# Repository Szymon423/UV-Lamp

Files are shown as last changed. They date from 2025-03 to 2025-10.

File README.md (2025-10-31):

<div align="center">

# 💅 UV Lamp Project

*A custom-made UV lamp for nail polish curing*

</div>

---

## 📖 About

In this project, I wanted to address a common issue in the beauty industry: **misleading UV lamp specifications**. 

Most commercial UV lamps are advertised as "60W UV lamps" while being supplied with only 15W power adapters. I wanted to create something honest and effective, so I designed this lamp from scratch.

### ✨ Key Features

- **True 45W electrical power** - honest specifications
- **Adjustable power settings** - customize intensity from 0-100%
- **Configurable timer** - set precise curing times up to 3 minutes
- **Intuitive touchscreen interface** - easy configuration with rotary encoder
- **Settings persistence** - preferences saved in flash memory
- **Professional UV wavelength** - 395-405nm LEDs for optimal curing

<div align="center">

### 🎨 Main Design

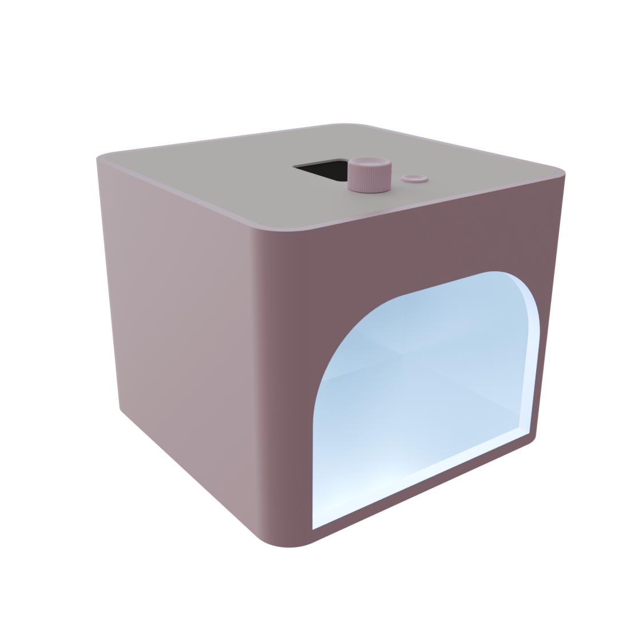
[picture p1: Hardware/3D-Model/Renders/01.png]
Main Render


### 🖼️ Detailed Views

<table>
  <tr>
    <td width="50%">
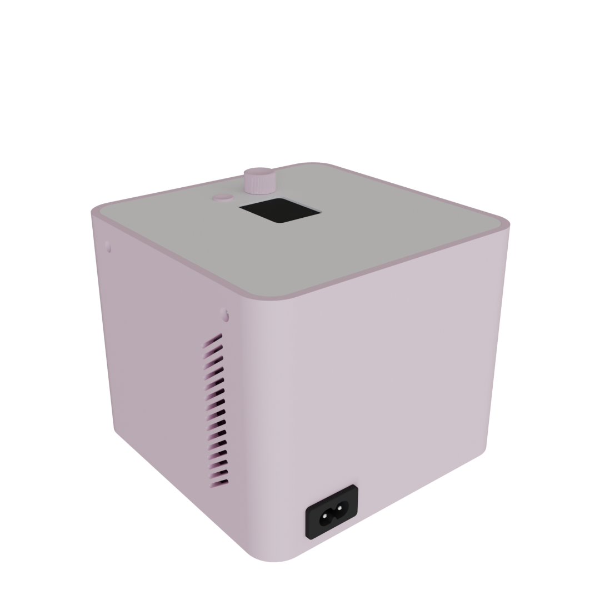
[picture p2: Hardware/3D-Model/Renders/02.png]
View 2
      
    </td>
    <td width="50%">
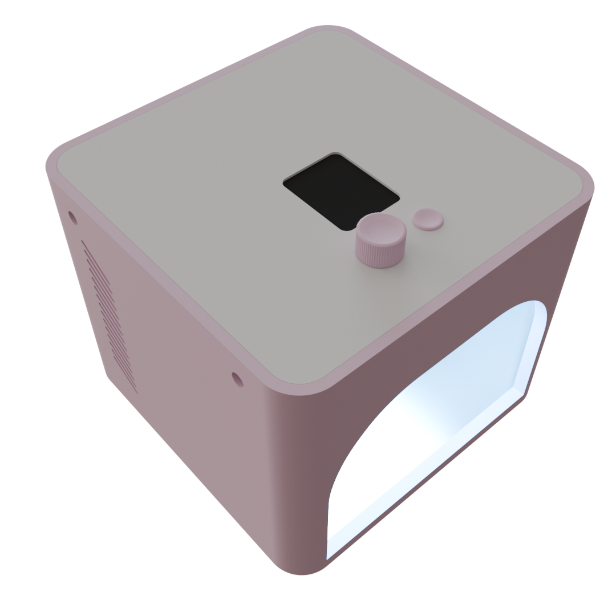
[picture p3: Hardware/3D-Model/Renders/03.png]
View 3
      
    </td>
  </tr>
  <tr>
    <td width="50%">
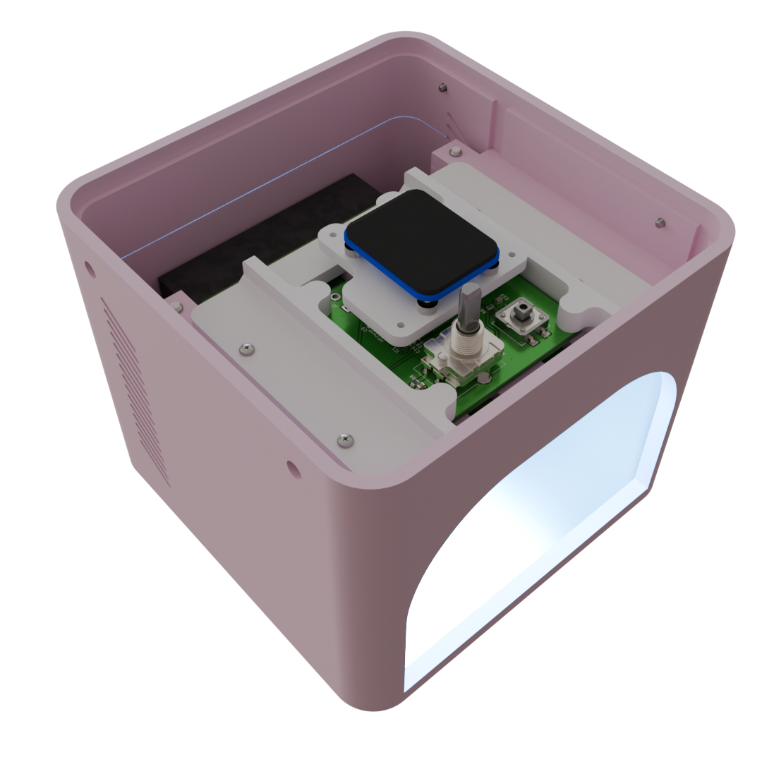
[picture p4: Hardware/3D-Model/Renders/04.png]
View 4
      
    </td>
    <td width="50%">
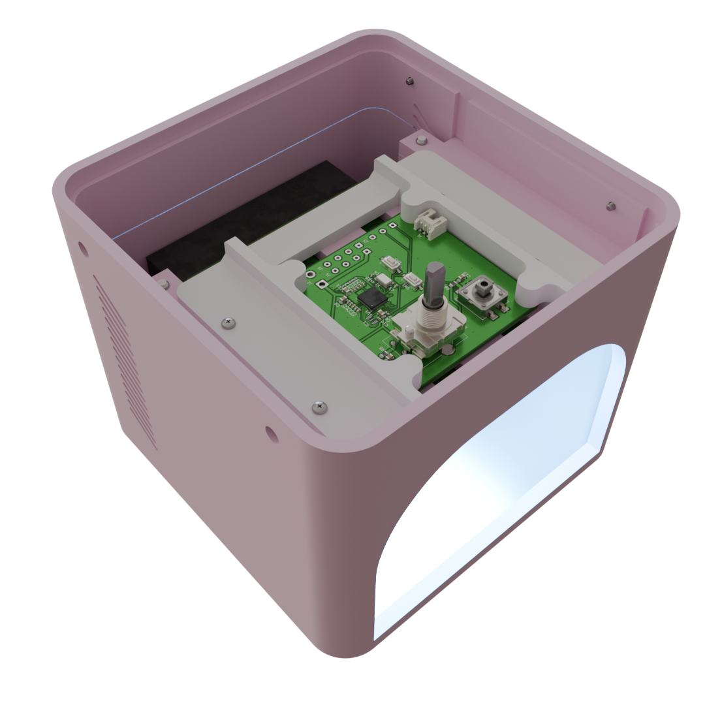
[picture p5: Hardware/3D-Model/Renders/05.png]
View 5
      
    </td>
  </tr>
  <tr>
    <td width="50%">
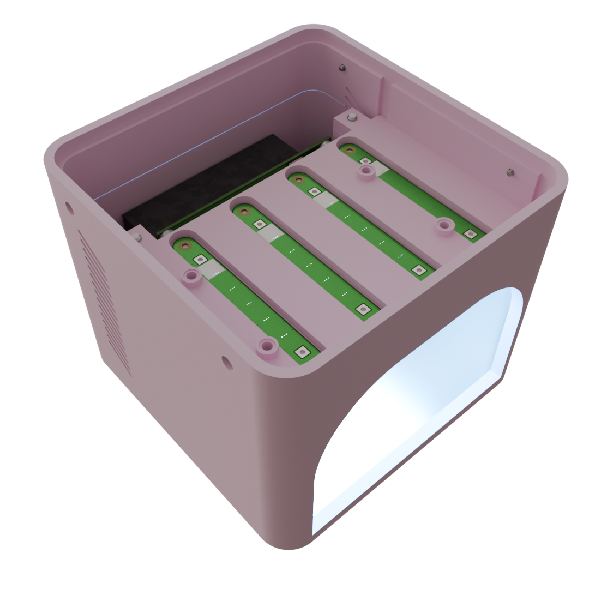
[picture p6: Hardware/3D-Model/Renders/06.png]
View 6
      
    </td>
    <td width="50%">
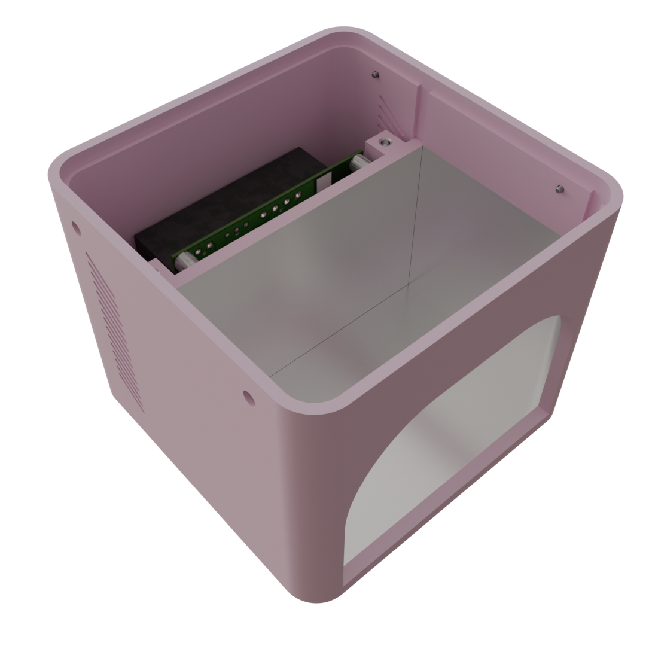
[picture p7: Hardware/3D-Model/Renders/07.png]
View 7
      
    </td>
  </tr>
  <tr>
    <td width="50%">
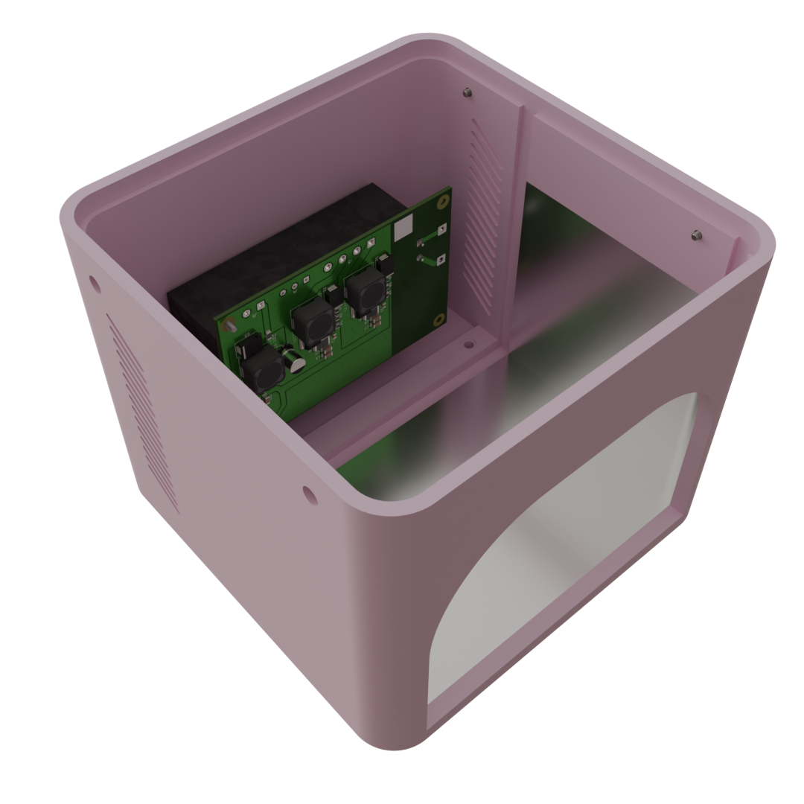
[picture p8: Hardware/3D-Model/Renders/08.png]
View 8
      
    </td>
    <td cwidth="50%">
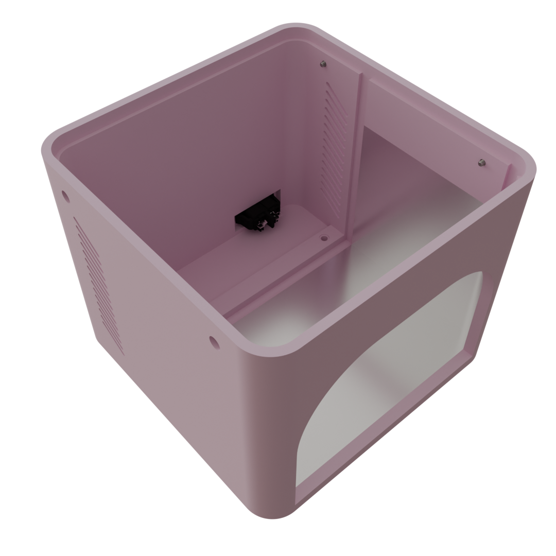
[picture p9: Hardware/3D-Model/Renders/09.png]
View 9
      
    </td>
  </tr>
</table>

</div>

---

## ⚡ Hardware Design

The hardware was designed in **KiCad** around the **Raspberry Pi RP2040** microcontroller. The lamp is powered through a C8 socket connector from 230V AC mains.

### 🔧 PCB Architecture

The system consists of three types of PCBs:

1. **Power & Driver Board**
   - Converts 230V AC to 48V DC for LED drivers
   - Provides 3.3V DC for microcontroller and peripherals
   - LED current drivers with PWM control capability

2. **Control Board**
   - RP2040 microcontroller
   - 1.69" LCD display with LVGL interface
   - Rotary encoder for navigation
   - Two control buttons
   - Flash memory for settings storage

3. **LED Arrays**
   - Multiple LED strings with 395-405nm wavelength
   - Optimized thermal management
   - Uniform light distribution

### 📊 Technical Specifications

- **Input voltage:** 230V AC (50/60Hz)
- **LED power:** 48V DC, up to 45W total
- **UV wavelength:** 395-405nm
- **Control:** PWM dimming, 0-100%
- **Timer range:** 0-180 seconds
- **Display:** 1.69" color LCD (280x240)

---

## 💻 Software

The firmware is written in C for the RP2040 and utilizes the following technologies:

### 🛠️ Core Technologies

- **LVGL (Light and Versatile Graphics Library)** - for the graphical interface
- **SquareLine Studio** - for UI design
- **Pico SDK** - official Raspberry Pi development kit
- **Hardware PWM** - for precise LED dimming control

### 🖥️ User Interface

<div align="center">

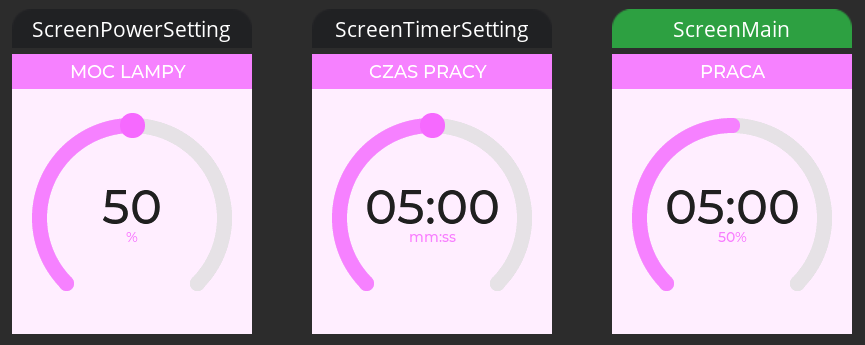
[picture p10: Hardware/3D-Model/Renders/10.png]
User Interface


</div>

The interface features three main screens:

1. **Main Screen** - displays current timer and power settings with arc progress indicator
2. **Power Configuration** - adjust UV intensity from 0-100%
3. **Timer Configuration** - set curing time from 0 to 180 seconds

### 🎮 Controls

- **Rotary Encoder** - navigate and adjust values
- **Button 1** - short press: change screen | long press: enter/exit edit mode
- **Button 2** - short press: start/pause timer | long press: reset timer

### 🚀 Features

- Smooth animations and transitions
- Real-time countdown with arc visualization
- Automatic settings save to flash memory
- Debounced button inputs with long-press detection
- 30 FPS refresh rate for fluid UI

---

## 📜 License

This project is open source. Feel free to use, modify, and distribute according to the license terms.

---

## 🙏 Acknowledgments

This project was created because my girlfriend complained about her unreliable UV lamp. It combines my passion for electronics and design with practical problem-solving.

---

<div align="center">

*Made with dedication to quality and honesty*

</div>

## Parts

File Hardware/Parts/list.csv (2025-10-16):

Symbol klienta | Symbol | Oznaczenie producenta | Producent | Ilość | Jednostka | Cena netto | Cena brutto | Wartość netto | Wartość brutto | Waluta
 | B3FS-4055P | B3FS-4055P | OMRON Electronic Components | 1 | szt | 4.89 | 6.01 | 4.89 | 6.01 | PLN
 | PEC16-4220F-S0024 | PEC16-4220F-S0024 | BOURNS | 1 | szt | 14.38 | 17.69 | 14.38 | 17.69 | PLN
 | IRM-60-48 | IRM-60-48 | MEAN WELL | 1 | szt | 54.88 | 67.5 | 54.88 | 67.5 | PLN
 | 3413.0119.22 | 3413.0119.22 | SCHURTER | 5 | szt | 1.744 | 10.73 | 8.72 | 10.73 | PLN
 | KAF31GR72A225KU | KAF31GR72A225KU | KYOCERA AVX | 10 | szt | 0.8 | 9.84 | 8 | 9.84 | PLN
 | ZSC00BM1011EARL | ZSC00BM1011EARL | VISHAY | 10 | szt | 0.643 | 7.91 | 6.43 | 7.91 | PLN
 | B560C-13-F | B560C-13-F | DIODES INCORPORATED | 4 | szt | 1.775 | 8.73 | 7.1 | 8.73 | PLN
 | DE1207-22 | DE1207-22 | FERROCORE | 5 | szt | 1.386 | 8.53 | 6.93 | 8.53 | PLN
 | CRCW080515K4FKTABC | CRCW080515K4FKTABC | VISHAY | 100 | szt | 0.0106 | 1.3 | 1.06 | 1.3 | PLN
 | CRCW0805316KFKTABC | CRCW0805316KFKTABC | VISHAY | 100 | szt | 0.1067 | 13.12 | 10.67 | 13.12 | PLN
 | SMD0805-36.5K-1% | 0805S8F3652T5E | ROYALOHM | 100 | szt | 0.0692 | 8.51 | 6.92 | 8.51 | PLN
 | ERA6AEB1152V | ERA6AEB1152V | PANASONIC | 10 | szt | 0.215 | 2.64 | 2.15 | 2.64 | PLN
 | TPS54560DDA | TPS54560DDA | TEXAS INSTRUMENTS | 1 | szt | 25.75 | 31.67 | 25.75 | 31.67 | PLN
 | 0805B822K500CT | 0805B822K500CT | WALSIN | 10 | szt | 0.166 | 2.04 | 1.66 | 2.04 | PLN
 | LM3409HVMY/NOPB | LM3409HVMY/NOPB | TEXAS INSTRUMENTS | 2 | szt | 9.28 | 22.83 | 18.56 | 22.83 | PLN
 | DMP10H400SK3-13 | DMP10H400SK3-13 | DIODES INCORPORATED | 3 | szt | 1.9167 | 7.07 | 5.75 | 7.07 | PLN
 | DE1207-47 | DE1207-47 | FERROCORE | 5 | szt | 1.334 | 8.21 | 6.67 | 8.21 | PLN
 | ERA6AEB6811V | ERA6AEB6811V | PANASONIC | 10 | szt | 0.212 | 2.61 | 2.12 | 2.61 | PLN
 | AR0805-24K9-0.1% | AR05BTCW2492 | Viking | 10 | szt | 0.433 | 5.32 | 4.33 | 5.32 | PLN
 | SMD0805-49K9-1% | 0805S8F4992T5E | ROYALOHM | 100 | szt | 0.0612 | 7.53 | 6.12 | 7.53 | PLN
 | CS2512-0R3-1%-HP | CS12FTFSR300 | Viking | 10 | szt | 1.152 | 14.17 | 11.52 | 14.17 | PLN
 | C0805C471K5RAC | C0805C471K5RACTU | KEMET | 100 | szt | 0.0629 | 7.74 | 6.29 | 7.74 | PLN
 | C0805C471K5RAC | C0805C471K5RACTU | KEMET | 100 | szt | 0.0629 | 7.74 | 6.29 | 7.74 | PLN
 | VS-30BQ100-M3/9AT | VS-30BQ100-M3/9AT | VISHAY | 10 | szt | 1.361 | 16.74 | 13.61 | 16.74 | PLN
 | PK2B-3LLE-GNVM | PK2B-3LLE-GNVM | ProLight Opto | 11 | szt | 6.04 | 81.72 | 66.44 | 81.72 | PLN
 | PK2B-3LLE-GNV | PK2B-3LLE-GNV | ProLight Opto | 11 | szt | 6.04 | 81.72 | 66.44 | 81.72 | PLN

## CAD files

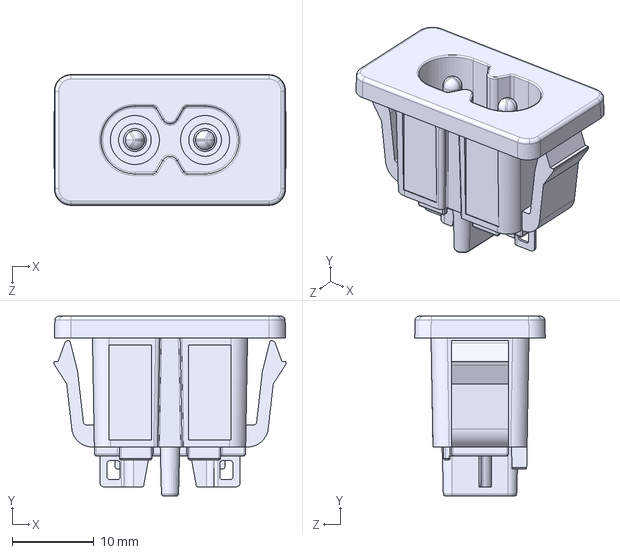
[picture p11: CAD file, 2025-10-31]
Hardware/3D-Model/Assets/4300-0102/4300.0102.stp
28.4 x 22.0 x 16.0 mm

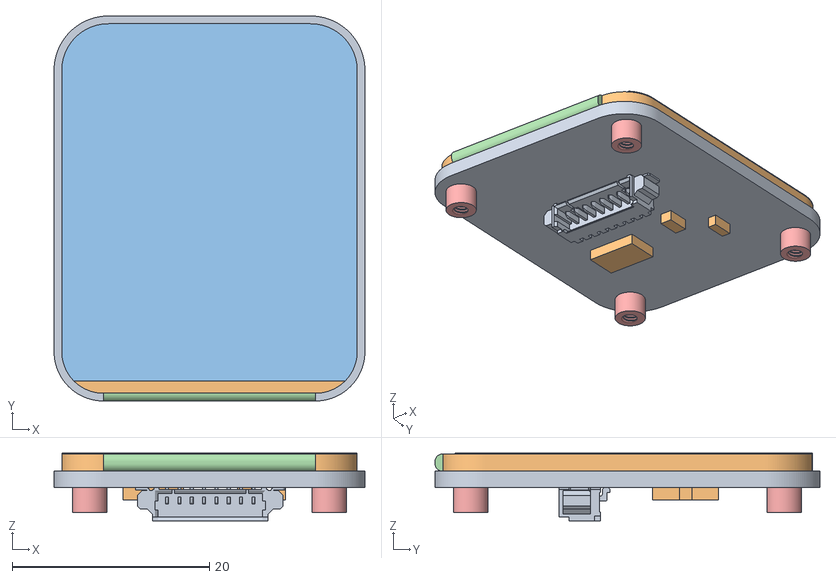
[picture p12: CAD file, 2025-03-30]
Hardware/3D-Model/Assets/WAVESHARE 1.69in IPS LCD.obj
31.5 x 39.0 x 6.88
obj1
obj2
obj3
obj4
obj5

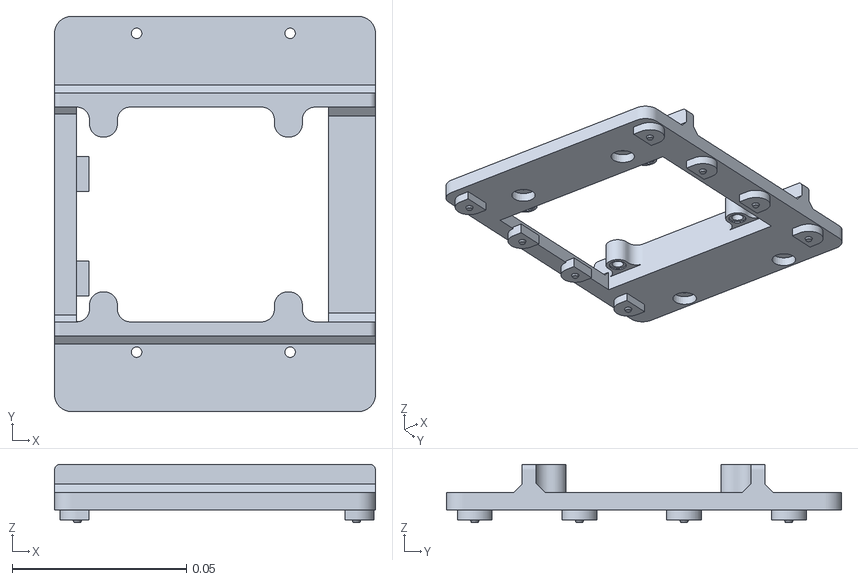
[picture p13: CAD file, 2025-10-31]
Hardware/3D-Model/Print-Models/03.stl
0.092 x 0.113 x 0.0167

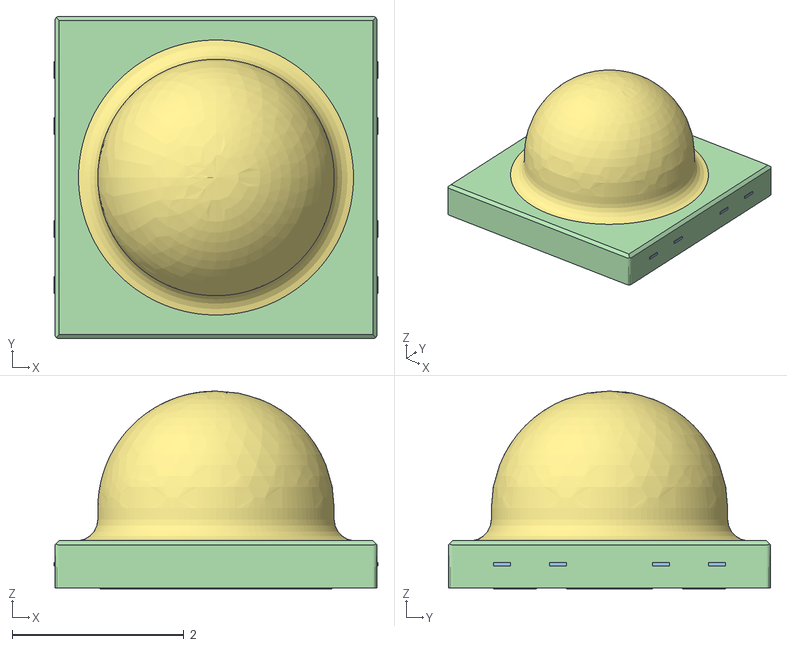
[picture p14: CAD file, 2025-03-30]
Hardware/3D-Model/Assets/LR H9GP.obj
3.77 x 3.75 x 2.30
obj1
obj2
obj3
obj4
obj5
obj6
obj7

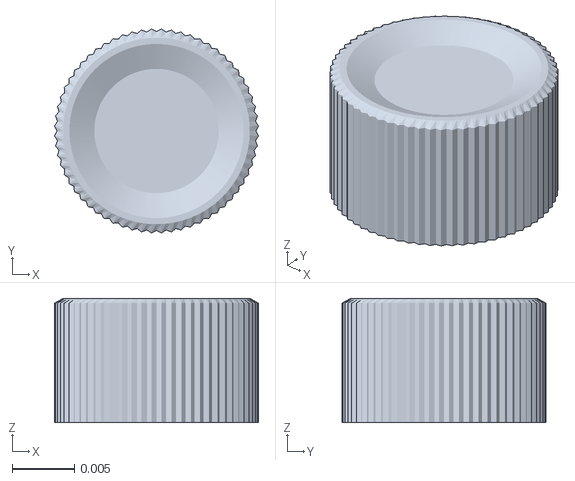
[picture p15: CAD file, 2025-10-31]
Hardware/3D-Model/Print-Models/08.stl
0.0164 x 0.0164 x 0.01

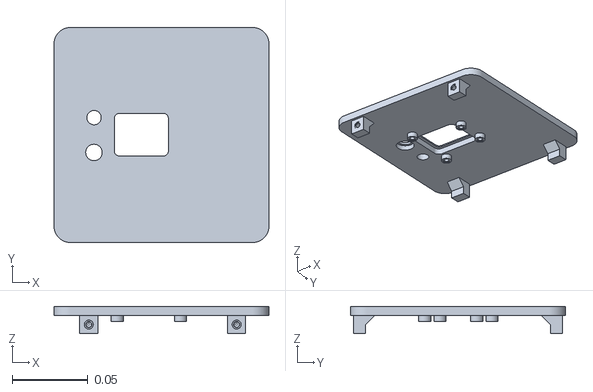
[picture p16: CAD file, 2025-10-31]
Hardware/3D-Model/Print-Models/05.stl
0.142 x 0.142 x 0.018

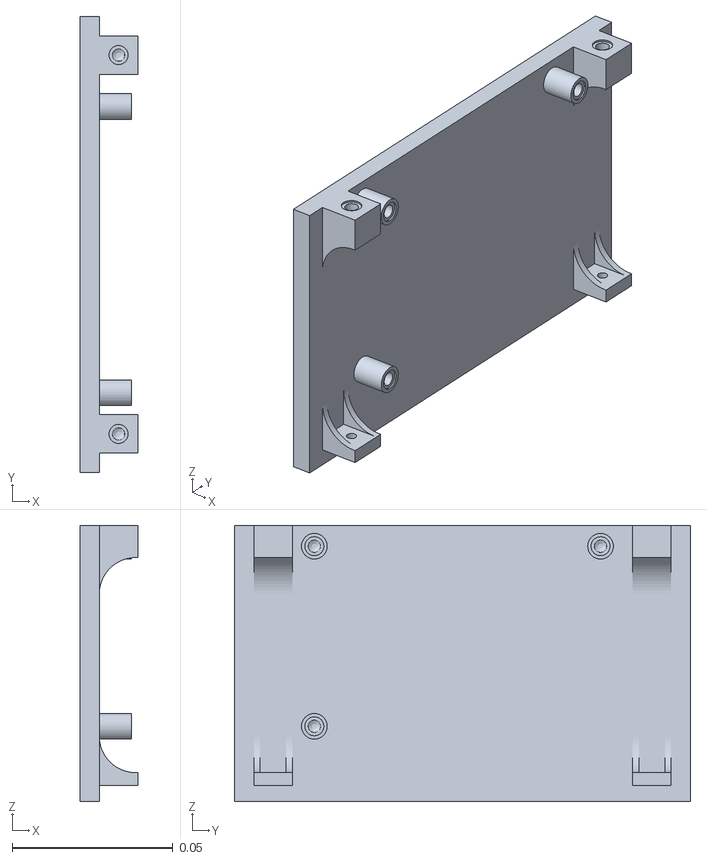
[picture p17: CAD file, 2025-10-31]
Hardware/3D-Model/Print-Models/02.stl
0.018 x 0.142 x 0.0859

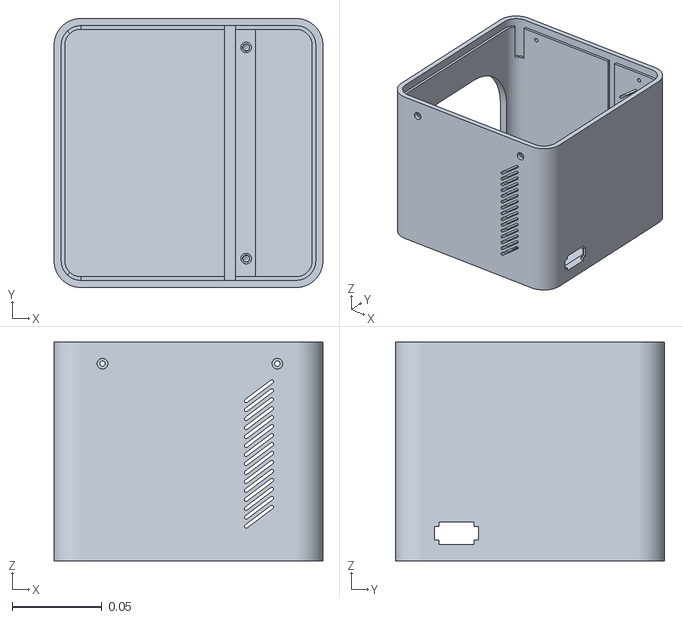
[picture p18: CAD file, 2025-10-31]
Hardware/3D-Model/Print-Models/01.stl
0.15 x 0.15 x 0.122

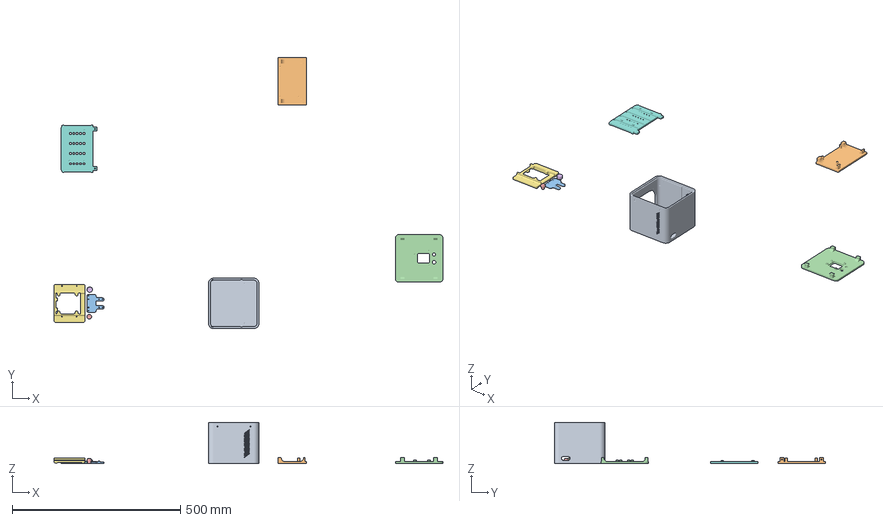
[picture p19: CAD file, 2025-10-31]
Hardware/3D-Model/Print-Models/print-setup.3mf
1156.7 x 806.4 x 122.0 mm
01.stl
02.stl
04.stl
05.stl
07.stl
08.stl
03.stl
06.stl

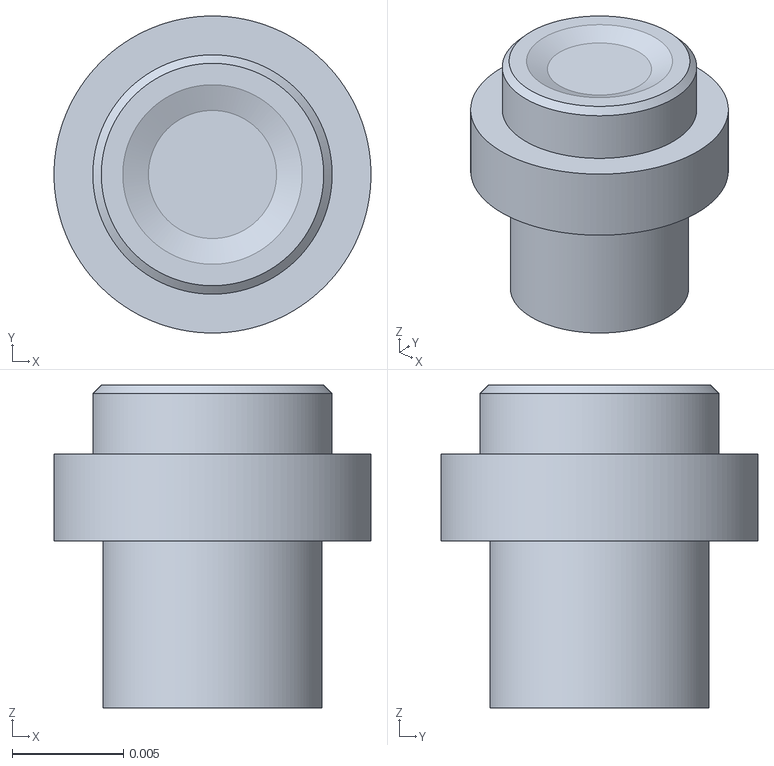
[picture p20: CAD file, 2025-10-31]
Hardware/3D-Model/Print-Models/07.stl
0.0143 x 0.0143 x 0.0145

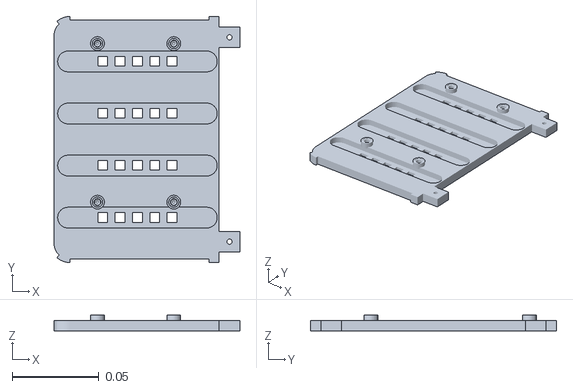
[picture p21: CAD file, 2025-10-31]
Hardware/3D-Model/Print-Models/06.stl
0.107 x 0.142 x 0.009

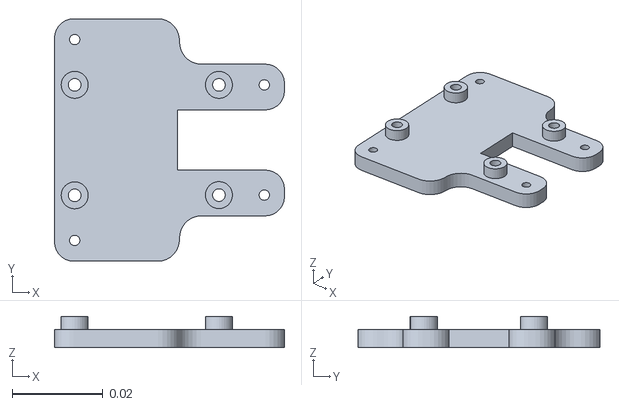
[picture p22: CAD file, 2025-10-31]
Hardware/3D-Model/Print-Models/04.stl
0.0507 x 0.0535 x 0.00688

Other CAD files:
Hardware/3D-Model/Assets/materials/laminated-wood_43ea55bd-042d-487e-ba9f-20deb624679f/laminated-wood_2K_e02dadd8-0ec0-419a-900f-228d0139f861.blend
Hardware/3D-Model/Assets/materials/marble_76c30967-3c26-4003-82ce-031fdcf77739/marble_2K_059a2f77-6672-4889-af9c-39595b21e0f0.blend
Hardware/3D-Model/Assets/materials/wood_7a947126-5460-49a4-bb98-ce3ba98e8168/wood_2K_ed4594c7-b028-4205-94dd-9be74723a804.blend
Hardware/3D-Model/Assets/materials/wood_f02d04dc-3e70-4cd1-8a19-36c7389b7842/wood_2K_d6103686-cbc8-4858-aa78-1b068617dfaf.blend

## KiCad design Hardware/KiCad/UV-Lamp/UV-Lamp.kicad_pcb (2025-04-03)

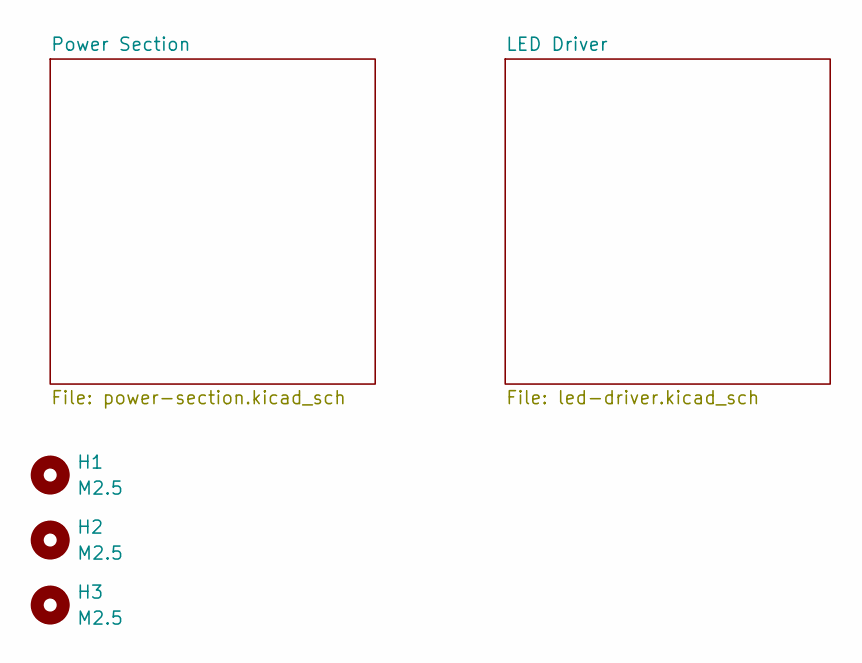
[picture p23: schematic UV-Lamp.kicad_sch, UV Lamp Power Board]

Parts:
H1, H2, H3: M2.5; MountingHole_2.7mm_M2.5

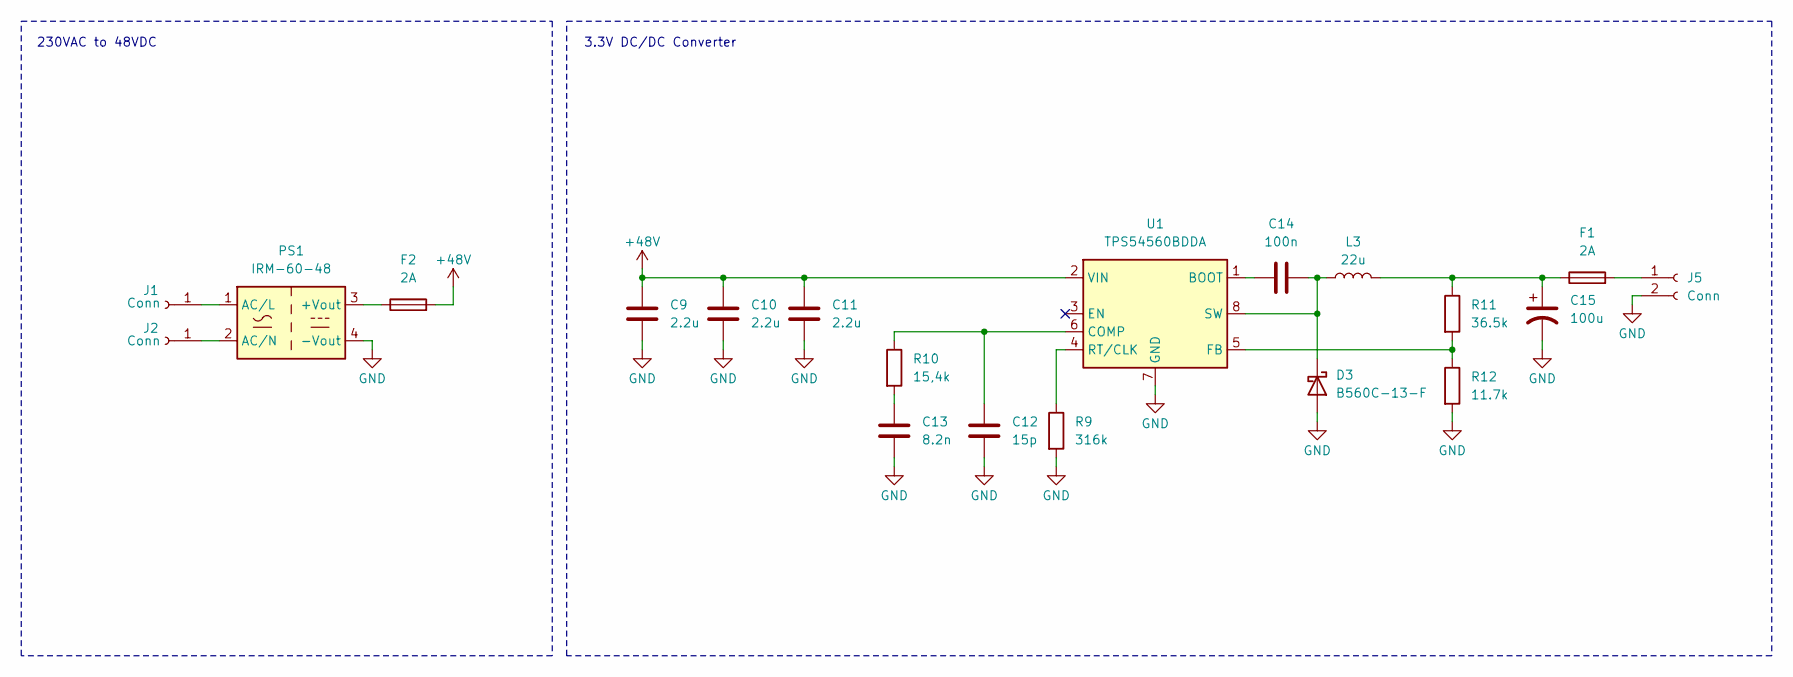
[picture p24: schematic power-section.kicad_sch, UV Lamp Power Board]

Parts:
C9, C10, C11: 2.2u; C_1206_3216Metric
C12: 15p; C_0805_2012Metric
C13: 8.2n; C_0805_2012Metric
C14: 100n; C_0805_2012Metric
C15: 100u; CP_Elec_6.3x7.7
D3: B560C-13-F; D_SMC
F1, F2: 2A; Fuse_1206_3216Metric
J1, J2: Conn; SolderWire-1.5sqmm_1x01_D1.7mm_OD3.9mm
J5: Conn; SolderWire-1sqmm_1x02_P5.4mm_D1.4mm_OD2.7mm
L3: 22u; L_12x12mm_H6mm
PS1: IRM-60-48; Converter_ACDC_MeanWell_IRM-60-xx_THT
R9: 316k; R_0805_2012Metric
R10: 15,4k; R_0805_2012Metric
R11: 36.5k; R_0805_2012Metric
R12: 11.7k; R_0805_2012Metric
U1: TPS54560BDDA; Texas_R-PDSO-G8_EP2.95x4.9mm_Mask2.4x3.1mm_ThermalVias

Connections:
+48V: C9.1, C10.1, C11.1, F2.2, U1.2 (VIN); also elsewhere on the board
GND: C9.2, C10.2, C11.2, C12.2, C13.2, C15.2, D3.2 (A), J5.2, PS1.4 (-Vout), R9.2, R12.2, U1.7 (GND), U1.9 (GND); also elsewhere on the board
unnamed: C13.1, R10.2
unnamed: C15.1, F1.1, L3.2, R11.1
unnamed: C14.2, D3.1 (K), L3.1, U1.8 (SW)
unnamed: J1.1, PS1.1 (AC/L)
unnamed: J2.1, PS1.2 (AC/N)
unnamed: F1.2, J5.1
unnamed: F2.1, PS1.3 (+Vout)
unnamed: C14.1, U1.1 (BOOT)
unnamed: C12.1, R10.1, U1.6 (COMP)
unnamed: R11.2, R12.1, U1.5 (FB)
unnamed: R9.1, U1.4 (RT/CLK)

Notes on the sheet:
230VAC to 48VDC
3.3V DC/DC Converter

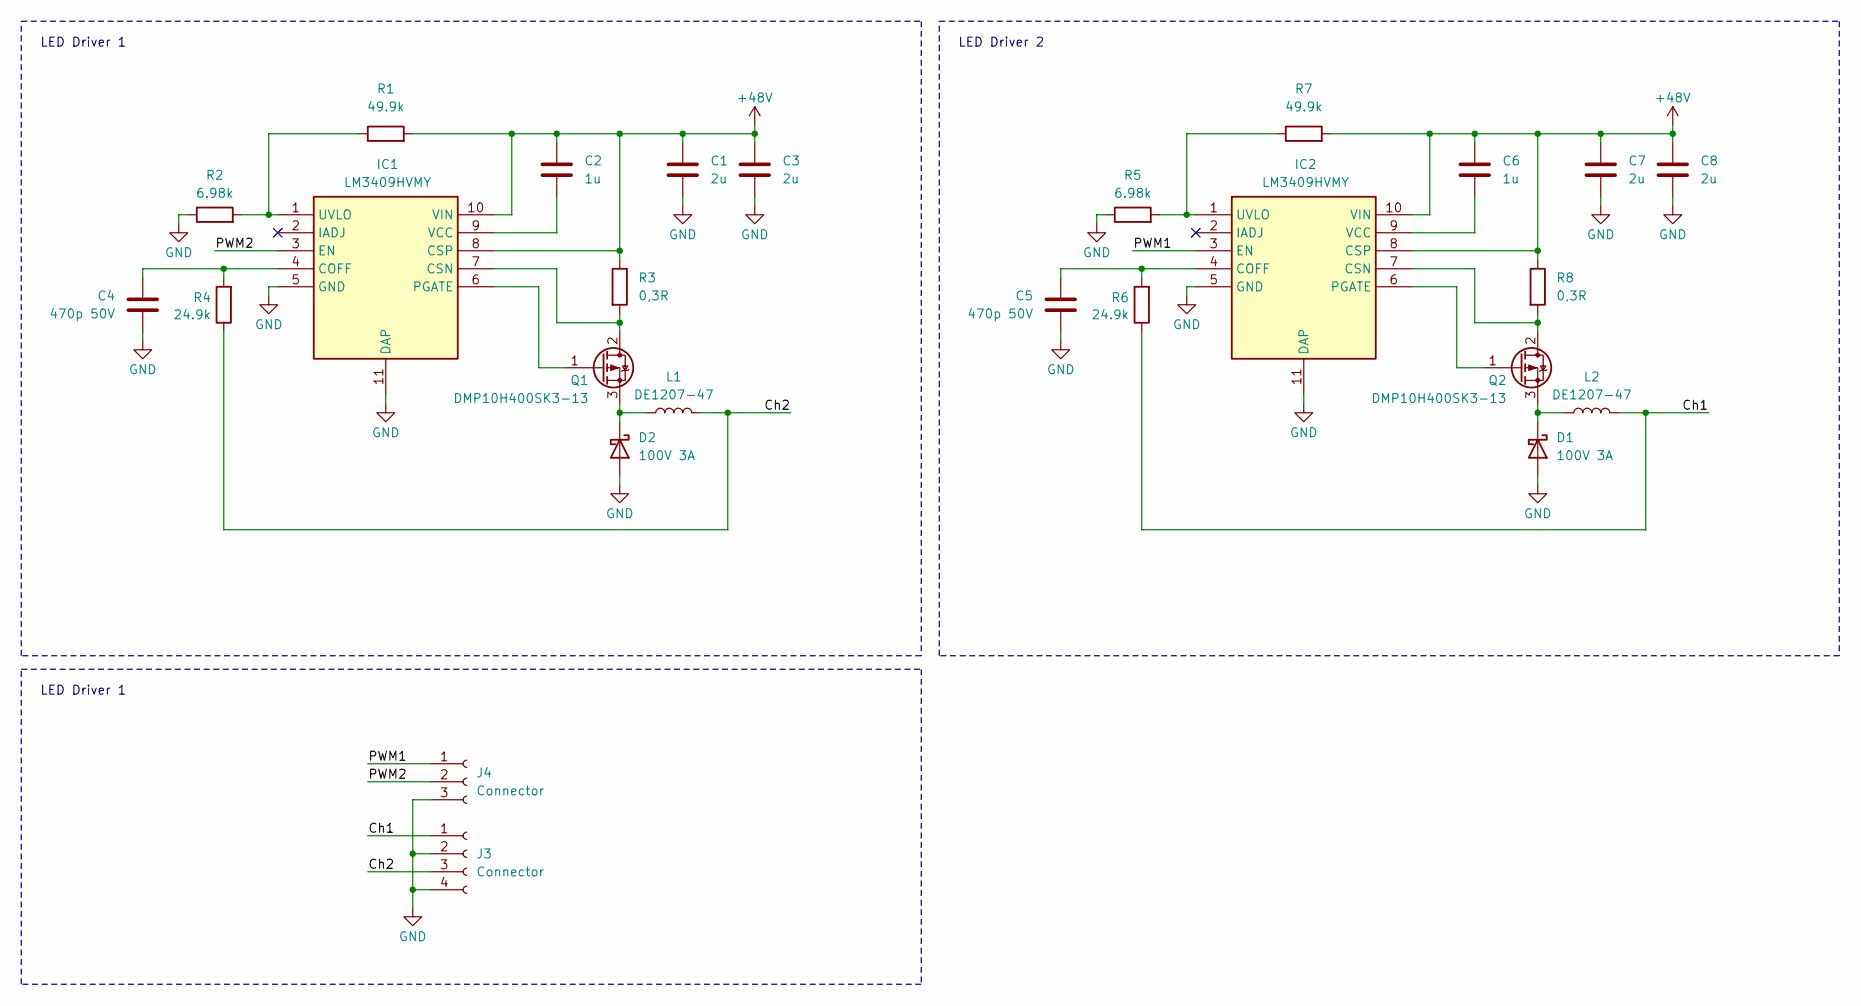
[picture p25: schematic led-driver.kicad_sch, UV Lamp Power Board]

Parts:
C1, C3, C7, C8: 2u; C_1206_3216Metric
C2, C6: 1u; C_0805_2012Metric
C4, C5: 470p 50V; C_0805_2012Metric
D1, D2: 100V 3A; D_SMC
IC1, IC2: LM3409HVMY; Manufacturer_Part_Number LM3409HVMY/NOPB
J3: Connector; SolderWire-1.5sqmm_1x04_P6mm_D1.7mm_OD3mm
J4: Connector; SolderWire-0.5sqmm_1x03_P4.6mm_D0.9mm_OD2.1mm
L1, L2: DE1207-47; L_12x12mm_H6mm
Q1, Q2: DMP10H400SK3-13; TO-252-2
R1, R7: 49.9k; R_0805_2012Metric
R2, R5: 6.98k; R_0805_2012Metric
R3, R8: 0,3R; R_2512_6332Metric
R4, R6: 24.9k; R_0805_2012Metric

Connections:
+48V: C1.1, C2.1, C3.1, C6.1, C7.1, C8.1, IC1.8 (CSP), IC1.10 (VIN), IC2.8 (CSP), IC2.10 (VIN), R1.2, R3.1, R7.2, R8.1; also elsewhere on the board
/LED Driver/Ch1: J3.1, L2.2, R6.1
/LED Driver/Ch2: J3.3, L1.2, R4.1
/LED Driver/PWM1: IC2.3 (EN), J4.1
/LED Driver/PWM2: IC1.3 (EN), J4.2
GND: C1.2, C3.2, C4.2, C5.2, C7.2, C8.2, D1.2 (A), D2.2 (A), IC1.5 (GND), IC1.11 (DAP), IC2.5 (GND), IC2.11 (DAP), J3.2, J3.4, J4.3, R2.1, R5.1; also elsewhere on the board
unnamed: D1.1 (K), L2.1, Q2.3 (S)
unnamed: D2.1 (K), L1.1, Q1.3 (S)
unnamed: C4.1, IC1.4 (COFF), R4.2
unnamed: IC1.7 (CSN), Q1.2 (D), R3.2
unnamed: IC1.6 (PGATE), Q1.1 (G)
unnamed: IC1.1 (UVLO), R1.1, R2.2
unnamed: C2.2, IC1.9 (VCC)
unnamed: C5.1, IC2.4 (COFF), R6.2
unnamed: IC2.7 (CSN), Q2.2 (D), R8.2
unnamed: IC2.6 (PGATE), Q2.1 (G)
unnamed: IC2.1 (UVLO), R5.2, R7.1
unnamed: C6.2, IC2.9 (VCC)

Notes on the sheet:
LED Driver 2
LED Driver 1

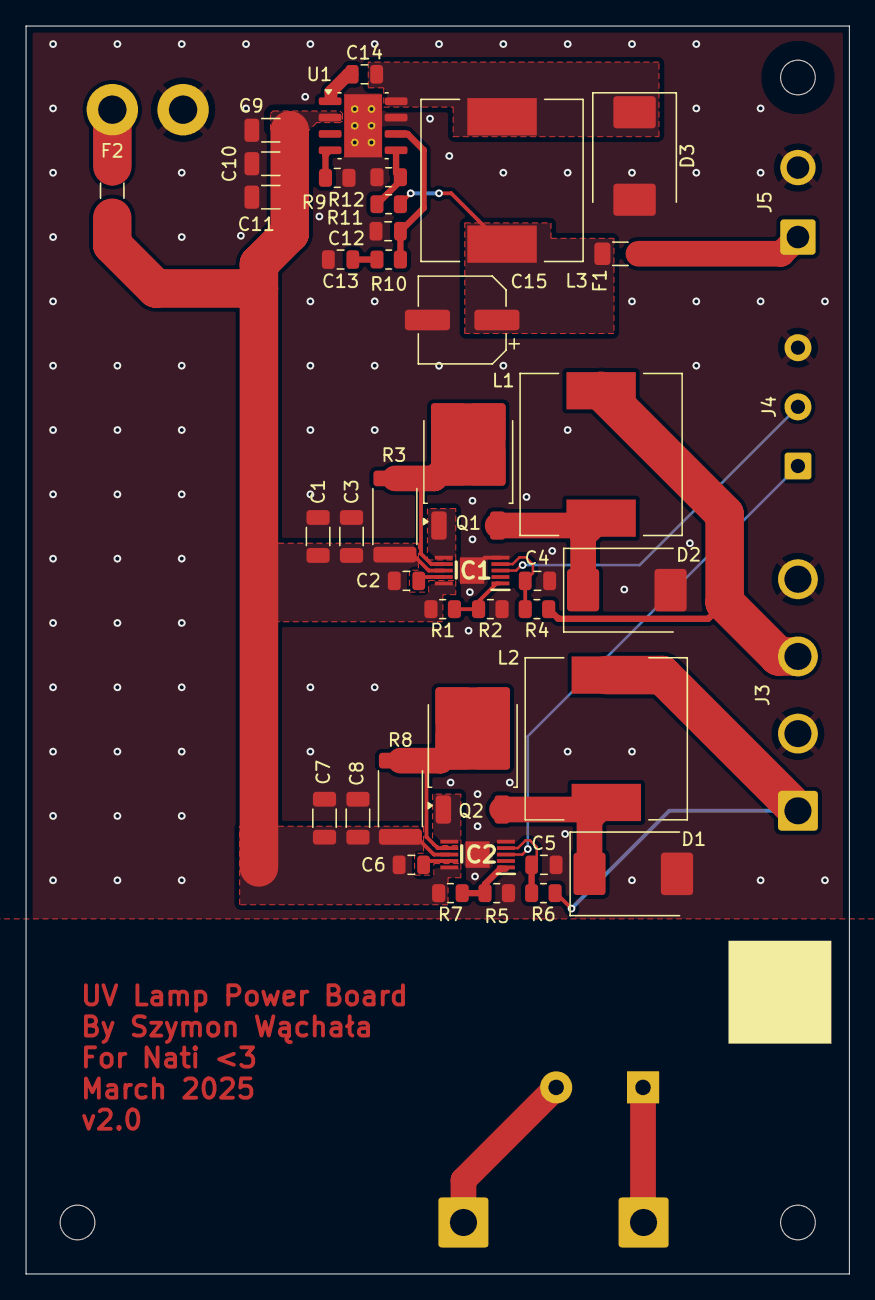
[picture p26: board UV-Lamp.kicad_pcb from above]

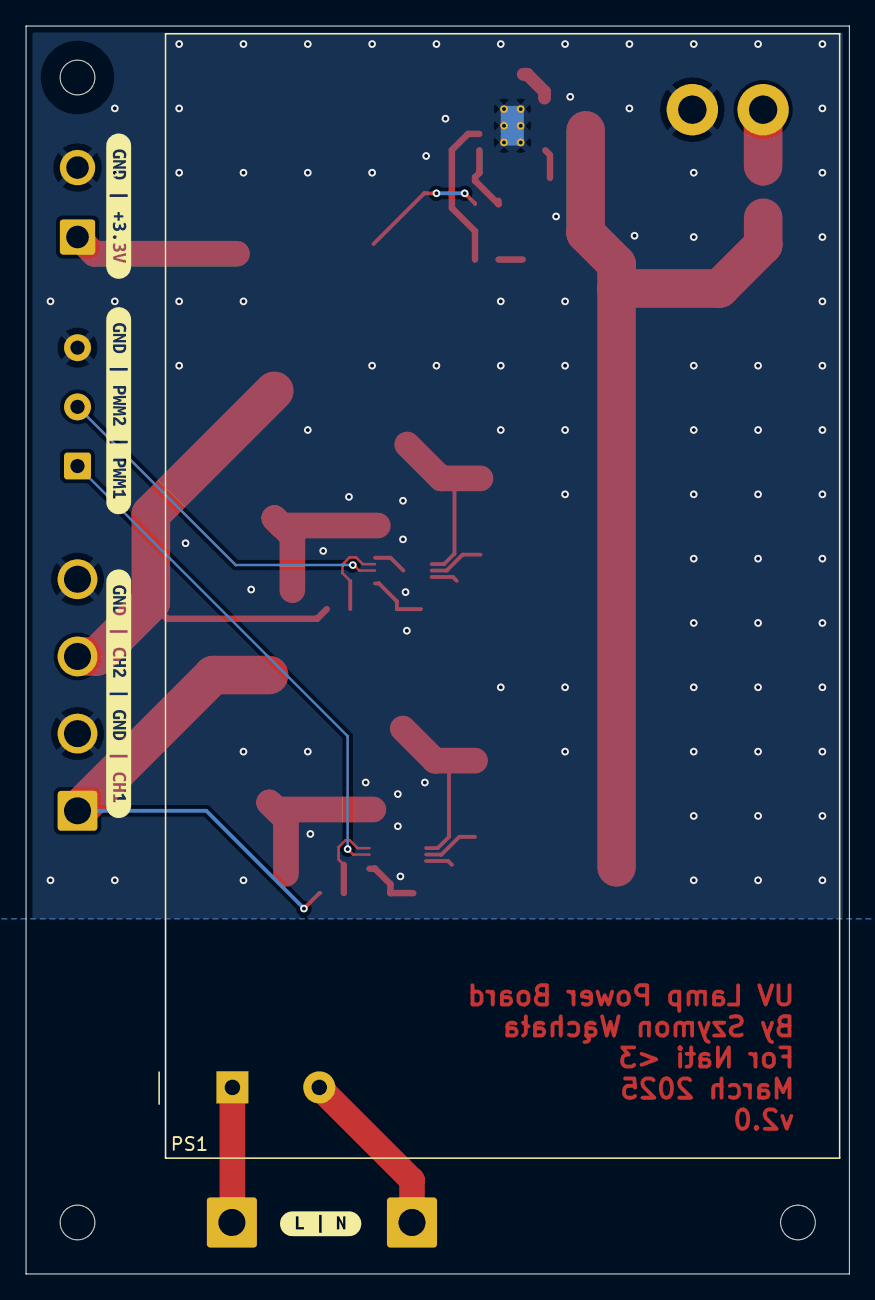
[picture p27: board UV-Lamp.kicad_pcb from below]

Board: 2 copper layers, 64.0 x 97.0 mm, 53 parts (5 on the bottom side), 29 nets.

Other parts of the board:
kibuzzard-67E995BA: G***; kibuzzard-67E995BA
kibuzzard-67E9956E: G***; kibuzzard-67E9956E
kibuzzard-67E99536: G***; kibuzzard-67E99536
kibuzzard-67E99669: G***; kibuzzard-67E99669

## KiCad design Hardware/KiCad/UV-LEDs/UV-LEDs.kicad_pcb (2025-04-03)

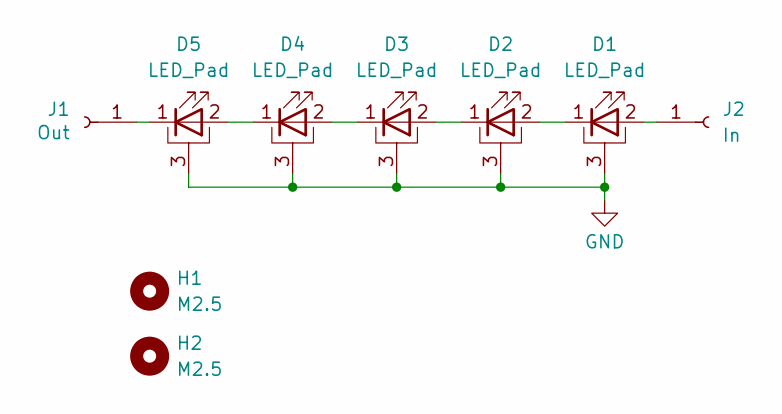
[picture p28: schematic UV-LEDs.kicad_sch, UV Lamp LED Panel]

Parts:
D1, D2, D3, D4, D5: LED_Pad; LED_Cree-XHP35
H1, H2: M2.5; MountingHole_2.7mm_M2.5
J1: Out; SolderWire-1.5sqmm_1x01_D1.7mm_OD3.9mm
J2: In; SolderWire-1.5sqmm_1x01_D1.7mm_OD3.9mm

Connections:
GND: D1.3 (PAD), D2.3 (PAD), D3.3 (PAD), D4.3 (PAD), D5.3 (PAD)
unnamed: D1.2 (A), J2.1
unnamed: D1.1 (K), D2.2 (A)
unnamed: D2.1 (K), D3.2 (A)
unnamed: D3.1 (K), D4.2 (A)
unnamed: D4.1 (K), D5.2 (A)
unnamed: D5.1 (K), J1.1

Board: 2 copper layers, 11 parts (0 on the bottom side), 7 nets, no tracks yet.

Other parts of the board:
kibuzzard-67E9A14C: G***; kibuzzard-67E9A14C
kibuzzard-67E9A164: G***; kibuzzard-67E9A164

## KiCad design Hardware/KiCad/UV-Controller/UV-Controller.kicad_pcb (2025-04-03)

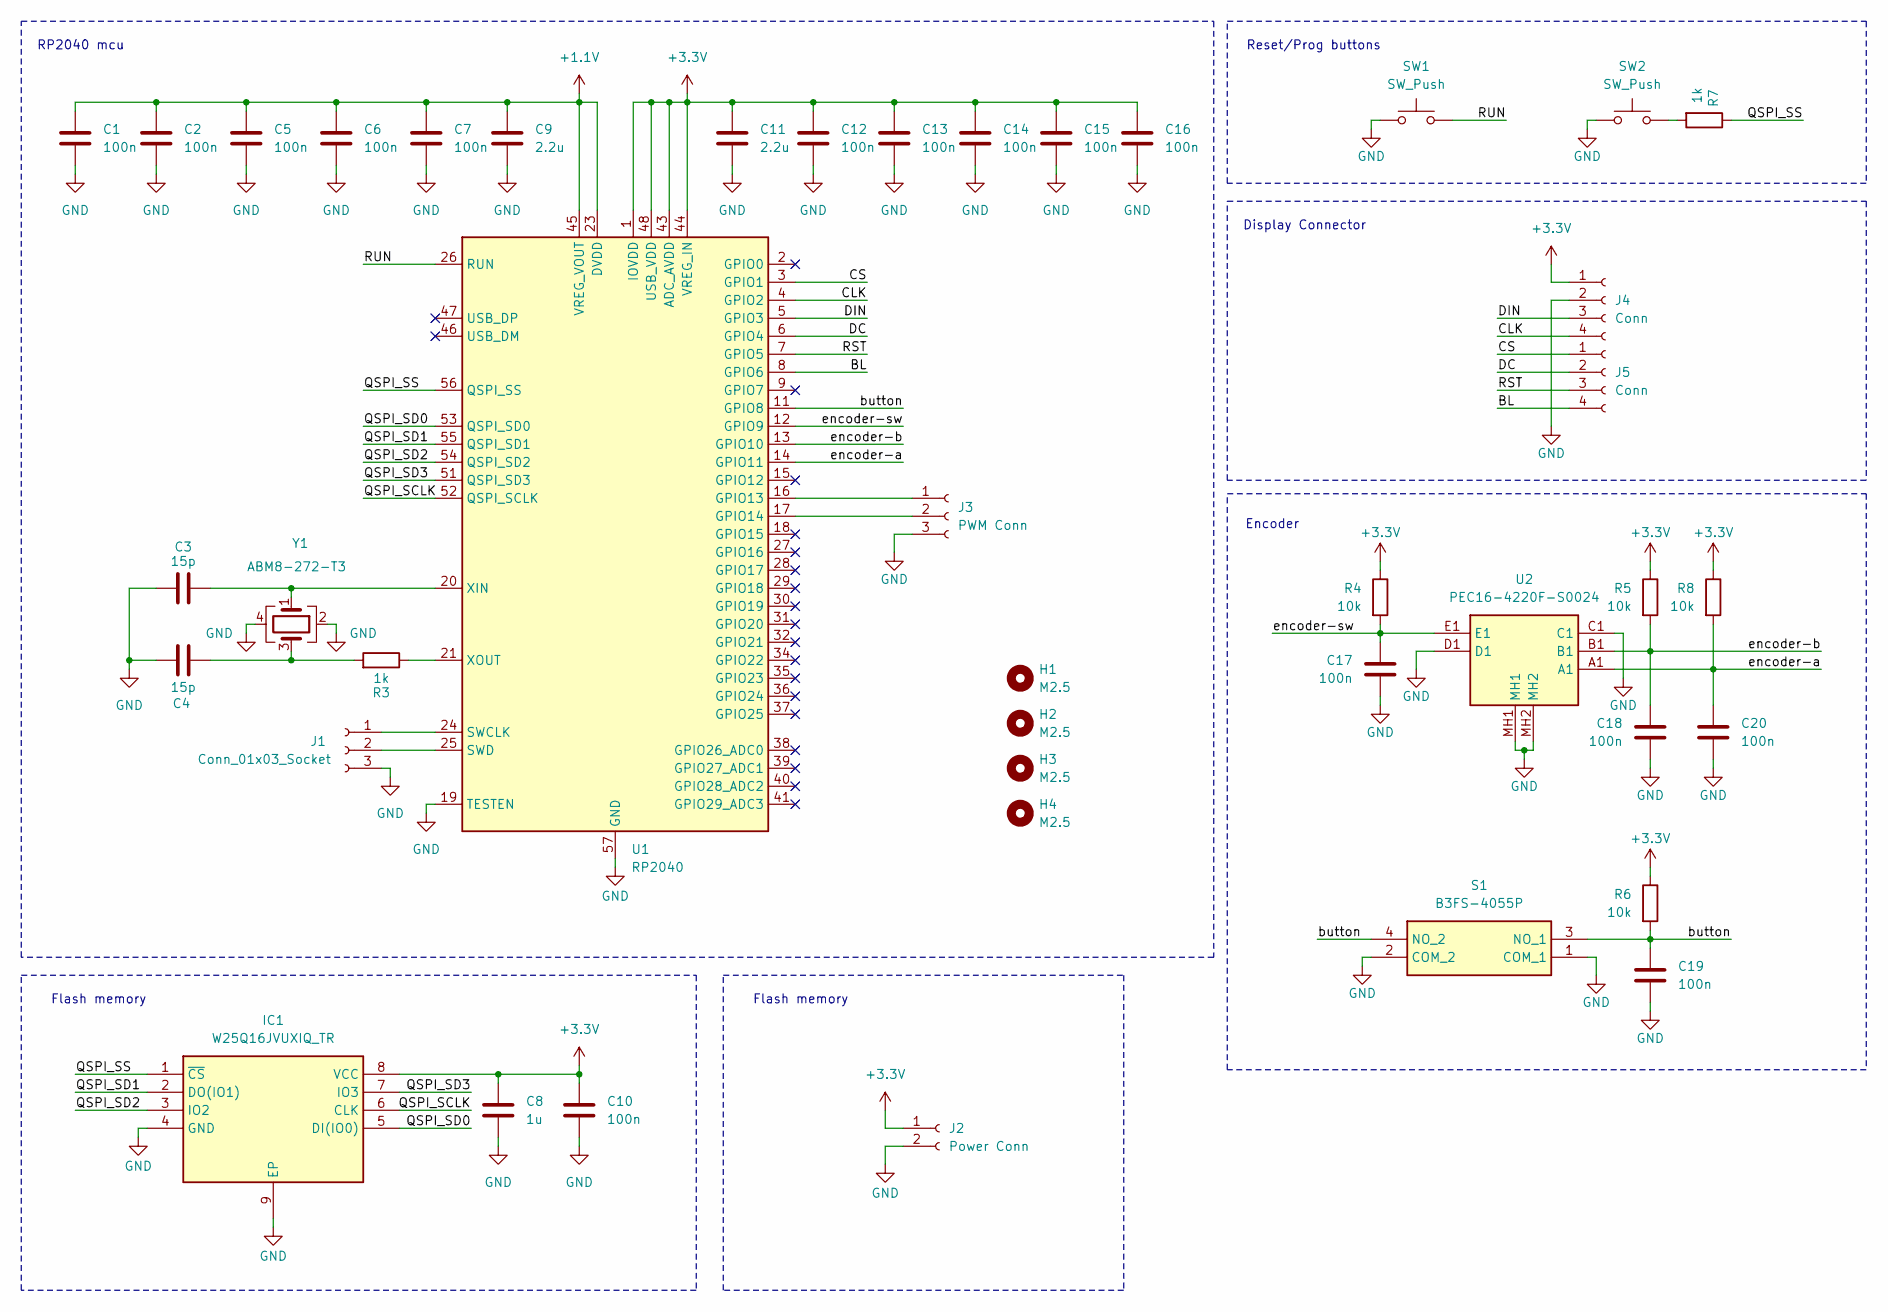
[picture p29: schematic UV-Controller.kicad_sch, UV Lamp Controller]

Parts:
C1, C2, C5, C6, C7, C10, C12, C13, C14, C15, C16: 100n; C_0402_1005Metric
C3, C4: 15p; C_0402_1005Metric
C8: 1u; C_0805_2012Metric
C9, C11: 2.2u; C_0805_2012Metric
C17, C18, C19, C20: 100n; C_0805_2012Metric
H1, H2, H3, H4: M2.5; MountingHole_2.7mm_M2.5
IC1: W25Q16JVUXIQ_TR; SON50P300X200X60-9N; Manufacturer_Part_Number W25Q16JVUXIQ TR
J1: Conn_01x03_Socket; JST_PH_S3B-PH-K_1x03_P2.00mm_Horizontal
J2: Power Conn; SolderWire-1.5sqmm_1x02_P6mm_D1.7mm_OD3mm
J3: PWM Conn; SolderWire-0.5sqmm_1x03_P4.6mm_D0.9mm_OD2.1mm
J4, J5: Conn; SolderWire-0.5sqmm_1x04_P4.6mm_D0.9mm_OD2.1mm
R3, R7: 1k; R_0402_1005Metric
R4, R5, R6, R8: 10k; R_0805_2012Metric
S1: B3FS-4055P; Manufacturer_Part_Number B3FS-4055P
SW1, SW2: SW_Push; SW_Tactile_SPST_NO_Straight_CK_PTS636Sx25SMTRLFS
U1: RP2040; QFN-56-1EP_7x7mm_P0.4mm_EP3.2x3.2mm_ThermalVias
U2: PEC16-4220F-S0024; Manufacturer_Part_Number PEC16-4220F-S0024
Y1: ABM8-272-T3; Crystal_SMD_Abracon_ABM3B-4Pin_5.0x3.2mm

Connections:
+1.1V: C1.1, C2.1, C5.1, C6.1, C7.1, C9.1, U1.23 (DVDD), U1.45 (VREG_VOUT), U1.50 (DVDD)
+3.3V: C8.1, C10.1, C11.1, C12.1, C13.1, C14.1, C15.1, C16.1, IC1.8 (VCC), J2.1, J4.1, R4.1, R5.1, R6.1, R8.1, U1.1 (IOVDD), U1.10 (IOVDD), U1.22 (IOVDD), U1.33 (IOVDD), U1.42 (IOVDD), U1.43 (ADC_AVDD), U1.44 (VREG_IN), U1.48 (USB_VDD), U1.49 (IOVDD)
/BL: J5.4, U1.8 (GPIO6)
/CLK: J4.4, U1.4 (GPIO2)
/CS: J5.1, U1.3 (GPIO1)
/DC: J5.2, U1.6 (GPIO4)
/DIN: J4.3, U1.5 (GPIO3)
/QSPI_SCLK: IC1.6 (CLK), U1.52 (QSPI_SCLK)
/QSPI_SD0: IC1.5 (DI(IO0)), U1.53 (QSPI_SD0)
/QSPI_SD1: IC1.2 (DO(IO1)), U1.55 (QSPI_SD1)
/QSPI_SD2: IC1.3 (IO2), U1.54 (QSPI_SD2)
/QSPI_SD3: IC1.7 (IO3), U1.51 (QSPI_SD3)
/QSPI_SS: IC1.1 (~CS), R7.1, U1.56 (QSPI_SS)
/RST: J5.3, U1.7 (GPIO5)
/RUN: SW1.2, U1.26 (RUN)
/button: C19.1, R6.2, S1.3 (NO_1), S1.4 (NO_2), U1.11 (GPIO8)
/encoder-a: C20.1, R8.2, U1.14 (GPIO11), U2.A1
/encoder-b: C18.1, R5.2, U1.13 (GPIO10), U2.B1
/encoder-sw: C17.1, R4.2, U1.12 (GPIO9), U2.E1
GND: C1.2, C2.2, C3.1, C4.1, C5.2, C6.2, C7.2, C8.2, C9.2, C10.2, C11.2, C12.2, C13.2, C14.2, C15.2, C16.2, C17.2, C18.2, C19.2, C20.2, IC1.4 (GND), IC1.9 (EP), J1.3, J2.2, J3.3, J4.2, S1.1 (COM_1), S1.2 (COM_2), SW1.1, SW2.1, U1.19 (TESTEN), U1.57 (GND), U2.C1, U2.D1, U2.MH1, U2.MH2, Y1.2, Y1.4
unnamed: C4.2, R3.2, Y1.3
unnamed: J1.1, U1.24 (SWCLK)
unnamed: J1.2, U1.25 (SWD)
unnamed: J3.1, U1.16 (GPIO13)
unnamed: J3.2, U1.17 (GPIO14)
unnamed: R7.2, SW2.2
unnamed: C3.2, U1.20 (XIN), Y1.1
unnamed: R3.1, U1.21 (XOUT)

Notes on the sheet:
Encoder
Display Connector
Flash memory
RP2040 mcu
Reset/Prog buttons

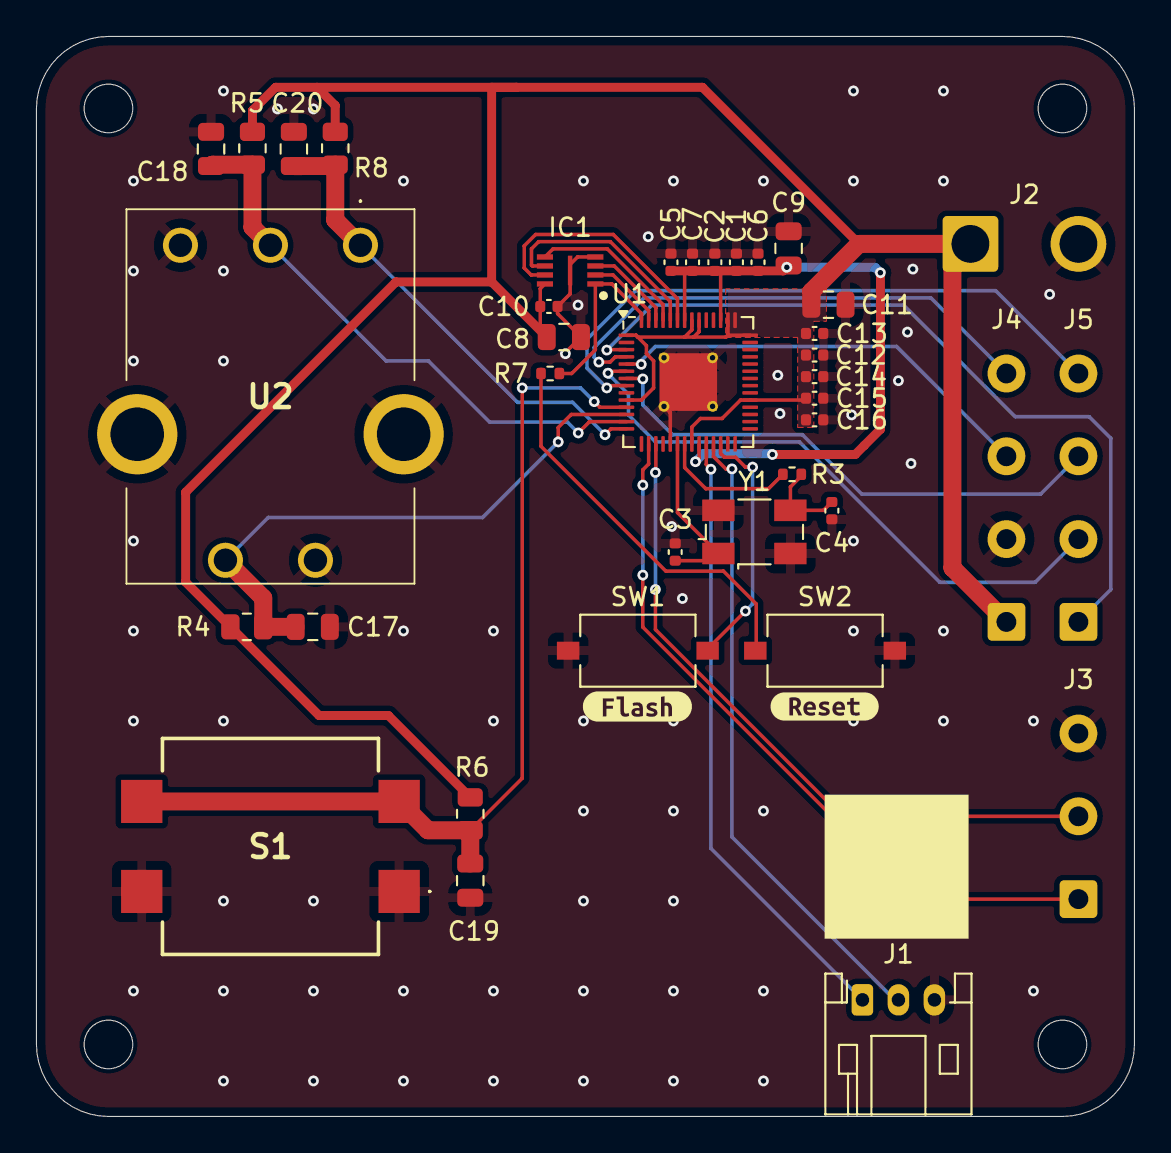
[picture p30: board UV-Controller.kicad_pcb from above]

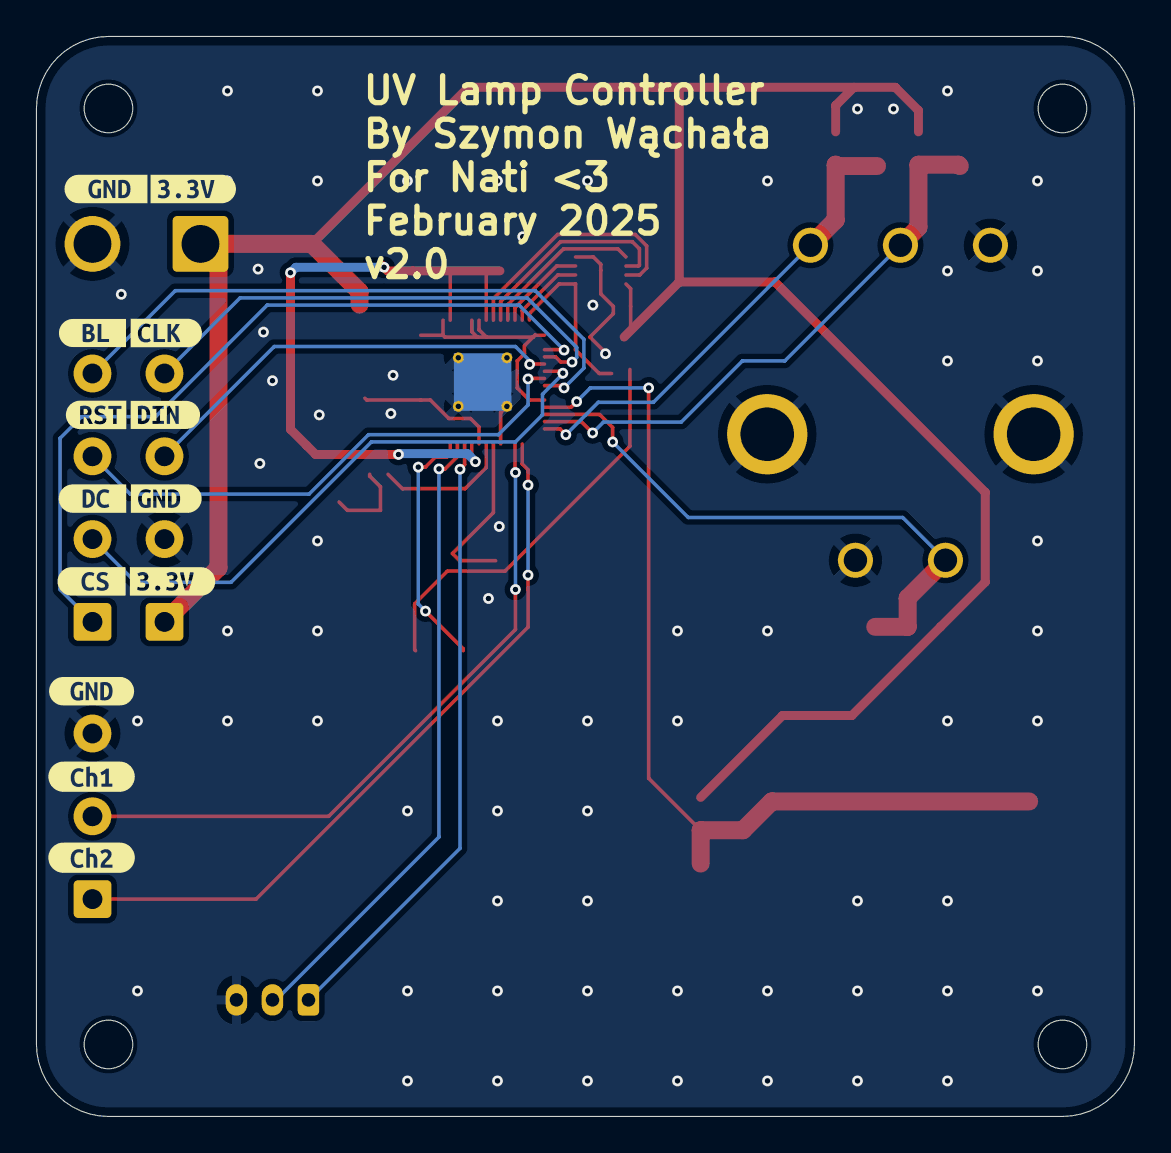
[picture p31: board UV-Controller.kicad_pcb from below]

Board: 2 copper layers, 61.0 x 60.0 mm, 57 parts (13 on the bottom side), 28 nets.

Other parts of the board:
kibuzzard-67EEDD31: G***; kibuzzard-67EEDD31
kibuzzard-67EEDD44: G***; kibuzzard-67EEDD44
kibuzzard-67EEDF74: G***; kibuzzard-67EEDF74
kibuzzard-67EEDFA4: G***; kibuzzard-67EEDFA4
kibuzzard-67EEDFD5: G***; kibuzzard-67EEDFD5
kibuzzard-67EEDFDD, kibuzzard-67EEDFDD#2: G***; kibuzzard-67EEDFDD
kibuzzard-67EEDFE5: G***; kibuzzard-67EEDFE5
kibuzzard-67EEDFEA: G***; kibuzzard-67EEDFEA
kibuzzard-67EEE00C: G***; kibuzzard-67EEE00C
kibuzzard-67EEE0EE: G***; kibuzzard-67EEE0EE
kibuzzard-67EEE001: G***; kibuzzard-67EEE001
kibuzzard-67EEE14D: G***; kibuzzard-67EEE14D
kibuzzard-67EEE147: G***; kibuzzard-67EEE147
kibuzzard-67EEE153: G***; kibuzzard-67EEE153

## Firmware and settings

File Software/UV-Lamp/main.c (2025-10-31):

#include "LCD_Test.h"
#include "LCD_1in69.h"
#include <stdio.h>
#include "pico/stdlib.h"
#include "lvgl.h"
#include "ui/ui.h"
#include "hardware/gpio.h"
#include "hardware/flash.h"
#include "hardware/sync.h"
#include "hardware/pwm.h" 

// ========================================
// KONFIGURACJA
// ========================================
#define TARGET_FPS 30
#define FRAME_TIME_MS (1000 / TARGET_FPS)

// GPIO PINY
#define ENC_A_PIN 10
#define ENC_B_PIN 11
#define BUTT1_PIN 9
#define BUTT2_PIN 8
#define PWM_CH1_PIN 13
#define PWM_CH2_PIN 14

// KONFIGURACJA PWM
#define PWM_FREQUENCY 1000  // 1 kHz
#define PWM_MAX_DUTY 65535  // 16-bit PWM (0-65535)

// ========================================
// KONFIGURACJA FLASH MEMORY
// ========================================
#define FLASH_TARGET_OFFSET (PICO_FLASH_SIZE_BYTES - FLASH_SECTOR_SIZE)  // Ostatni sektor flash
#define FLASH_MAGIC_NUMBER 0xABCD1234  // Numer magiczny do weryfikacji danych

typedef struct {
    uint32_t magic;              // Numer magiczny do weryfikacji
    uint8_t timer_value;         // Wartość timera (0-180)
    uint8_t power_value;         // Wartość mocy (0-100)
    uint16_t reserved;           // Zarezerwowane dla przyszłych użyć
} flash_config_t;

// Konfiguracja przycisków
#define DEBOUNCE_TIME_MS 10
#define LONG_PRESS_TIME_MS 1000

// Konfiguracja timera
#define ARC_UPDATE_INTERVAL_MS 100  // Aktualizacja arcu co 100ms dla płynności

// ========================================
// BUFORY DLA LVGL
// ========================================
static lv_disp_draw_buf_t draw_buf;
static lv_color_t buf1[LCD_1IN69_WIDTH * 70];

// ========================================
// ZMIENNE GLOBALNE
// ========================================
static uint8_t current_screen = 0;
static uint8_t configured_timer_value = 0;
static uint8_t configured_power_value = 0;

// Zmienne dla enkodera
static volatile int8_t encoder_delta = 0;
static volatile uint8_t encoder_last_state = 0;

// Zmienne dla przycisków
static volatile bool butt1_pressed = false;
static volatile bool butt2_pressed = false;
static volatile uint64_t butt1_press_time = 0;
static volatile uint64_t butt2_press_time = 0;
static volatile bool butt1_handled = false;
static volatile bool butt2_handled = false;

// Tryb edycji
static bool edit_mode = false;

// ========================================
// ZMIENNE DLA TIMERA
// ========================================
static bool timer_running = false;
static uint32_t timer_remaining_ms = 0;  // Pozostały czas w milisekundach
static uint64_t last_timer_update = 0;   // Ostatnia aktualizacja timera (ms)
static uint64_t last_arc_update = 0;     // Ostatnia aktualizacja arcu (ms)

// ZMIENNE DLA PWM
static uint pwm_slice_ch1;
static uint pwm_slice_ch2;
static uint pwm_chan_ch1;
static uint pwm_chan_ch2;

// ========================================
// INICJALIZACJA PWM
// ========================================
void init_pwm(void)
{
    // Konfiguracja PWM dla CH1 (pin 13)
    gpio_set_function(PWM_CH1_PIN, GPIO_FUNC_PWM);
    pwm_slice_ch1 = pwm_gpio_to_slice_num(PWM_CH1_PIN);
    pwm_chan_ch1 = pwm_gpio_to_channel(PWM_CH1_PIN);
    
    // Konfiguracja PWM dla CH2 (pin 14)
    gpio_set_function(PWM_CH2_PIN, GPIO_FUNC_PWM);
    pwm_slice_ch2 = pwm_gpio_to_slice_num(PWM_CH2_PIN);
    pwm_chan_ch2 = pwm_gpio_to_channel(PWM_CH2_PIN);
    
    // Ustawienie częstotliwości PWM
    // Clock system: 125 MHz
    // Dla 1 kHz: wrap = 125000 / 1000 = 125
    uint32_t clock_freq = 125000000;  // 125 MHz
    uint32_t divider = clock_freq / (PWM_FREQUENCY * PWM_MAX_DUTY);
    if (divider < 1) divider = 1;
    
    // Konfiguracja slice dla CH1
    pwm_config config_ch1 = pwm_get_default_config();
    pwm_config_set_clkdiv(&config_ch1, (float)divider);
    pwm_config_set_wrap(&config_ch1, PWM_MAX_DUTY - 1);
    pwm_init(pwm_slice_ch1, &config_ch1, false); 
    
    // Konfiguracja slice dla CH2
    pwm_config config_ch2 = pwm_get_default_config();
    pwm_config_set_clkdiv(&config_ch2, (float)divider);
    pwm_config_set_wrap(&config_ch2, PWM_MAX_DUTY - 1);
    pwm_init(pwm_slice_ch2, &config_ch2, false); 
    
    // Ustaw początkowe duty cycle na 0
    pwm_set_chan_level(pwm_slice_ch1, pwm_chan_ch1, 0);
    pwm_set_chan_level(pwm_slice_ch2, pwm_chan_ch2, 0);
}

// ========================================
// AKTUALIZACJA DUTY CYCLE PWM
// ========================================
void update_pwm_duty(uint8_t power_percent)
{
    // Przelicz procent mocy (0-100) na duty cycle (0-65535)
    uint16_t duty = (power_percent * PWM_MAX_DUTY) / 100;
    
    // Ustaw duty cycle dla obu kanałów
    pwm_set_chan_level(pwm_slice_ch1, pwm_chan_ch1, duty);
    pwm_set_chan_level(pwm_slice_ch2, pwm_chan_ch2, duty);
}

// ========================================
// START PWM
// ========================================
void start_pwm(void)
{
    update_pwm_duty(configured_power_value);
    pwm_set_enabled(pwm_slice_ch1, true);
    pwm_set_enabled(pwm_slice_ch2, true);
}

// ========================================
// STOP PWM
// ========================================
void stop_pwm(void)
{
    pwm_set_enabled(pwm_slice_ch1, false);
    pwm_set_enabled(pwm_slice_ch2, false);
    
    // Ustaw duty cycle na 0 dla bezpieczeństwa
    pwm_set_chan_level(pwm_slice_ch1, pwm_chan_ch1, 0);
    pwm_set_chan_level(pwm_slice_ch2, pwm_chan_ch2, 0);
}

// ========================================
// ODCZYT KONFIGURACJI Z FLASH
// ========================================
bool load_config_from_flash(void)
{
    const flash_config_t *flash_data = (const flash_config_t *)(XIP_BASE + FLASH_TARGET_OFFSET);
    
    // Sprawdź numer magiczny
    if (flash_data->magic == FLASH_MAGIC_NUMBER) {
        // Dane są prawidłowe
        configured_timer_value = flash_data->timer_value;
        configured_power_value = flash_data->power_value;
        
        // Walidacja zakresu (na wypadek uszkodzonych danych)
        if (configured_timer_value > 180) configured_timer_value = 0;
        if (configured_power_value > 100) configured_power_value = 0;
        
        return true;
    }
    
    // Brak prawidłowych danych - użyj wartości domyślnych
    configured_timer_value = 0;
    configured_power_value = 0;
    return false;
}

// ========================================
// ZAPIS KONFIGURACJI DO FLASH
// ========================================
void save_config_to_flash(void)
{
    flash_config_t config;
    config.magic = FLASH_MAGIC_NUMBER;
    config.timer_value = configured_timer_value;
    config.power_value = configured_power_value;
    config.reserved = 0;
    
    // Bufor musi być wyrównany do rozmiaru strony flash (256 bajtów)
    uint8_t buffer[FLASH_PAGE_SIZE];
    memset(buffer, 0xFF, FLASH_PAGE_SIZE);  // Wypełnij 0xFF (stan skasowanej pamięci)
    memcpy(buffer, &config, sizeof(flash_config_t));
    
    // Wyłącz przerwania podczas operacji flash
    uint32_t ints = save_and_disable_interrupts();
    
    // Skasuj sektor (4096 bajtów)
    flash_range_erase(FLASH_TARGET_OFFSET, FLASH_SECTOR_SIZE);
    
    // Zapisz dane (256 bajtów)
    flash_range_program(FLASH_TARGET_OFFSET, buffer, FLASH_PAGE_SIZE);
    
    // Przywróć przerwania
    restore_interrupts(ints);
}

// ========================================
// FUNKCJA WYŚWIETLANIA OBSZARU LCD
// ========================================
void LCD_1IN69_DisplayArea(UWORD Xstart, UWORD Ystart, UWORD Xend, UWORD Yend, UWORD *Image)
{
    UWORD width = Xend - Xstart + 1;
    UWORD height = Yend - Ystart + 1;
    UWORD total_pixels = width * height;
    
    LCD_1IN69_SetWindows(Xstart, Ystart, Xend, Yend);
    
    DEV_Digital_Write(LCD_DC_PIN, 1);
    DEV_Digital_Write(LCD_CS_PIN, 0);
    
    DEV_SPI_Write_nByte((uint8_t *)Image, total_pixels * 2);
    
    DEV_Digital_Write(LCD_CS_PIN, 1);
}

// ========================================
// CALLBACK FLUSH DLA LVGL
// ========================================
void my_disp_flush(lv_disp_drv_t *disp, const lv_area_t *area, lv_color_t *color_p)
{
    LCD_1IN69_DisplayArea(area->x1, area->y1, area->x2, area->y2, (UWORD *)color_p);
    lv_disp_flush_ready(disp);
}

// ========================================
// TIMER CALLBACK DLA LVGL TICK
// ========================================
bool lvgl_timer_callback(struct repeating_timer *t)
{
    lv_tick_inc(1);
    return true;
}

// ========================================
// ZARZĄDZANIE WIDOCZNOŚCIĄ ARKÓW
// ========================================
void update_arc_visibility(void)
{
    if (edit_mode) {
        // Pokaż arki w trybie edycji
        if (current_screen == 1) {
            lv_obj_clear_flag(ui_ArcPowerValue, LV_OBJ_FLAG_HIDDEN);
        } else if (current_screen == 2) {
            lv_obj_clear_flag(ui_ArcTimeValue, LV_OBJ_FLAG_HIDDEN);
        }
    } else {
        // Ukryj arki poza trybem edycji
        lv_obj_add_flag(ui_ArcPowerValue, LV_OBJ_FLAG_HIDDEN);
        lv_obj_add_flag(ui_ArcTimeValue, LV_OBJ_FLAG_HIDDEN);
        
        // Zapisz konfigurację do flash przy wyjściu z trybu edycji
        save_config_to_flash(); 
    }
}

// ========================================
// AKTUALIZACJA WYŚWIETLACZA TIMERA
// ========================================
void update_timer_display(void)
{
    char timerText[16];
    int minutes = configured_timer_value / 60;
    int seconds = configured_timer_value % 60;
    snprintf(timerText, sizeof(timerText), "%02d:%02d", minutes, seconds);
    lv_label_set_text(ui_LabelConfigTimerValue, timerText);
    int16_t arc_val = configured_timer_value * 10 / 18;
    lv_arc_set_value(ui_ArcTimeValue, arc_val);
}

// ========================================
// AKTUALIZACJA WYŚWIETLACZA MOCY
// ========================================
void update_power_display(void)
{
    char powerText[4];
    snprintf(powerText, sizeof(powerText), "%d", configured_power_value);
    lv_arc_set_value(ui_ArcPowerValue, configured_power_value);
    lv_label_set_text(ui_LabelPowerValue, powerText);
}

// ========================================
// AKTUALIZACJA ARCU NA EKRANIE GŁÓWNYM
// ========================================
void update_main_arc(void)
{
    if (configured_timer_value > 0) {
        // Oblicz procent wypełnienia arcu na podstawie milisekund
        uint32_t total_ms = configured_timer_value * 1000;
        int16_t arc_percent = (timer_remaining_ms * 100) / total_ms;
        
        // Ogranicz do zakresu 0-100
        if (arc_percent > 100) arc_percent = 100;
        if (arc_percent < 0) arc_percent = 0;
        
        lv_arc_set_value(ui_ArcMainTimerValue, arc_percent);
    } else {
        lv_arc_set_value(ui_ArcMainTimerValue, 0);
    }
}

// ========================================
// AKTUALIZACJA ETYKIETY CZASU NA EKRANIE GŁÓWNYM
// ========================================
void update_main_label(void)
{
    char timerText[16];
    uint32_t seconds = timer_remaining_ms / 1000;
    int minutes = seconds / 60;
    int secs = seconds % 60;
    snprintf(timerText, sizeof(timerText), "%02d:%02d", minutes, secs);
    lv_label_set_text(ui_LabelMainTimerValue, timerText);
}

// ========================================
// AKTUALIZACJA EKRANU GŁÓWNEGO (PEŁNA)
// ========================================
void update_main_display(void)
{
    // Aktualizacja wartości mocy
    char powerText[8];
    snprintf(powerText, sizeof(powerText), "%d%%", configured_power_value);
    lv_label_set_text(ui_LabelPowerValueSet, powerText);
    
    // Aktualizacja wartości timera i arcu
    update_main_label();
    update_main_arc();
}

// ========================================
// RESET TIMERA
// ========================================
void reset_timer(void)
{
    timer_running = false;
    timer_remaining_ms = configured_timer_value * 1000;
    last_timer_update = 0;
    last_arc_update = 0;
    update_main_display();
}

// ========================================
// START/PAUSE TIMERA
// ========================================
void toggle_timer(void)
{
    if (timer_running) {
        // Zatrzymaj timer
        timer_running = false;
        stop_pwm();
    } else {
        // Uruchom timer
        if (timer_remaining_ms > 0) {
            timer_running = true;
            last_timer_update = time_us_64() / 1000;
            last_arc_update = last_timer_update;
            
            start_pwm();
        }
    }
}

// ========================================
// OBSŁUGA TIMERA W GŁÓWNEJ PĘTLI
// ========================================
void process_timer(void)
{
    if (!timer_running || current_screen != 0) {
        return;
    }
    
    uint64_t current_time = time_us_64() / 1000; // czas w ms
    uint64_t elapsed = current_time - last_timer_update;
    
    if (elapsed > 0) {
        last_timer_update = current_time;
        
        // Odejmij upłynięty czas
        if (timer_remaining_ms > elapsed) {
            timer_remaining_ms -= elapsed;
        } else {
            // Timer zakończony
            timer_remaining_ms = 0;
            timer_running = false;
            
            // Zatrzymaj PWM po zakończeniu timera
            stop_pwm();  
            
            // Automatyczny reset do wartości początkowej
            timer_remaining_ms = configured_timer_value * 1000;
            update_main_display();
            
            return; // Zakończ funkcję, nie aktualizuj już wyświetlacza
        }
        
        // Aktualizuj etykietę co sekundę (gdy zmienia się wartość w sekundach)
        static uint32_t last_displayed_seconds = 0xFFFFFFFF;
        uint32_t current_seconds = timer_remaining_ms / 1000;
        
        if (current_seconds != last_displayed_seconds) {
            update_main_label();
            last_displayed_seconds = current_seconds;
        }
        
        // Aktualizuj arc częściej (co ARC_UPDATE_INTERVAL_MS)
        if (current_time - last_arc_update >= ARC_UPDATE_INTERVAL_MS) {
            update_main_arc();
            last_arc_update = current_time;
        }
    }
}

// ========================================
// WSPÓLNY CALLBACK GPIO (ENKODER I PRZYCISKI)
// ========================================
void gpio_callback(uint gpio, uint32_t events)
{
    // Obsługa enkodera
    if (gpio == ENC_A_PIN || gpio == ENC_B_PIN) {
        uint8_t enc_a = gpio_get(ENC_A_PIN);
        uint8_t enc_b = gpio_get(ENC_B_PIN);
        uint8_t current_state = (enc_a << 1) | enc_b;
        
        // Dekodowanie kierunku obrotu (Gray code)
        uint8_t combined = (encoder_last_state << 2) | current_state;
        
        switch(combined) {
            case 0b0001: case 0b0111: case 0b1110: case 0b1000:
                encoder_delta++;
                break;
            case 0b0010: case 0b0100: case 0b1101: case 0b1011:
                encoder_delta--;
                break;
        }
        
        encoder_last_state = current_state;
    }
    // Obsługa przycisków
    else if (gpio == BUTT1_PIN) {
        uint64_t current_time = time_us_64() / 1000; // czas w ms
        
        if (events & GPIO_IRQ_EDGE_FALL) {
            // Przycisk wciśnięty
            butt1_pressed = true;
            butt1_press_time = current_time;
            butt1_handled = false;
        } else if (events & GPIO_IRQ_EDGE_RISE) {
            // Przycisk zwolniony
            butt1_pressed = false;
        }
    } else if (gpio == BUTT2_PIN) {
        uint64_t current_time = time_us_64() / 1000; // czas w ms
        
        if (events & GPIO_IRQ_EDGE_FALL) {
            butt2_pressed = true;
            butt2_press_time = current_time;
            butt2_handled = false;
        } else if (events & GPIO_IRQ_EDGE_RISE) {
            butt2_pressed = false;
        }
    }
}

// ========================================
// INICJALIZACJA GPIO (ENKODER I PRZYCISKI)
// ========================================
void init_gpio(void)
{
    // Inicjalizacja enkodera
    gpio_init(ENC_A_PIN);
    gpio_init(ENC_B_PIN);
    gpio_set_dir(ENC_A_PIN, GPIO_IN);
    gpio_set_dir(ENC_B_PIN, GPIO_IN);
    gpio_pull_up(ENC_A_PIN);
    gpio_pull_up(ENC_B_PIN);
    
    // Inicjalizacja przycisków
    gpio_init(BUTT1_PIN);
    gpio_init(BUTT2_PIN);
    gpio_set_dir(BUTT1_PIN, GPIO_IN);
    gpio_set_dir(BUTT2_PIN, GPIO_IN);
    gpio_pull_up(BUTT1_PIN);
    gpio_pull_up(BUTT2_PIN);
    
    // Odczytaj początkowy stan enkodera
    encoder_last_state = (gpio_get(ENC_A_PIN) << 1) | gpio_get(ENC_B_PIN);
    
    // Ustawienie przerwań z jednym wspólnym callbackiem
    gpio_set_irq_enabled_with_callback(ENC_A_PIN, GPIO_IRQ_EDGE_RISE | GPIO_IRQ_EDGE_FALL, true, &gpio_callback);
    gpio_set_irq_enabled(ENC_B_PIN, GPIO_IRQ_EDGE_RISE | GPIO_IRQ_EDGE_FALL, true);
    gpio_set_irq_enabled(BUTT1_PIN, GPIO_IRQ_EDGE_RISE | GPIO_IRQ_EDGE_FALL, true);
    gpio_set_irq_enabled(BUTT2_PIN, GPIO_IRQ_EDGE_RISE | GPIO_IRQ_EDGE_FALL, true);
}

// ========================================
// OBSŁUGA ENKODERA W GŁÓWNEJ PĘTLI
// ========================================
void process_encoder(void)
{
    if (encoder_delta == 0) {
        return;
    }
    
    int8_t delta = encoder_delta;
    encoder_delta = 0;
    
    // Obsługa enkodera tylko w trybie edycji
    if (!edit_mode) {
        return;
    }
    
    if (current_screen == 1) {
        // Ekran konfiguracji mocy
        int16_t new_value = configured_power_value + delta;
        if (new_value < 0) new_value = 0;
        if (new_value > 100) new_value = 100;
        configured_power_value = new_value;
        update_power_display();
        
    } else if (current_screen == 2) {
        // Ekran konfiguracji timera
        int16_t new_value = configured_timer_value + delta;
        if (new_value < 0) new_value = 0;
        if (new_value > 180) new_value = 180;
        configured_timer_value = new_value;
        update_timer_display();
    }
}
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
int main(void) 
{
    sleep_ms(100);  // Stabilizacja po starcie
    
    // Inicjalizacja hardware
    if (!init_hardware()) {
        while(1) { tight_loop_contents(); }  // Zatrzymaj się w przypadku błędu
    }
    
    // Inicjalizacja LVGL
    if (!init_lvgl()) {
        while(1) { tight_loop_contents(); }  // Zatrzymaj się w przypadku błędu
    }
    
    // Inicjalizacja UI
    init_ui_timers();
    
    // Główna pętla
    main_loop();
    
    // Cleanup (nigdy nie powinno się tu dojść)
    DEV_Module_Exit();
    return 0;
}

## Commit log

2025-04-02 Designed simple enclosure
    [laminated-wood_2K_e02dadd8-0ec0-419a-900f-228d0139f861.blend, marble_2K_059a2f77-6672-4889-af9c-39595b21e0f0.blend, wood_2K_d6103686-cbc8-4858-aa78-1b068617dfa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]
2025-04-03 Prepared gerbers for prod
    [UV-Controller-B_Cu.gbl, UV-Controller-B_Mask.gbs, UV-Controller-B_Paste.gbp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]
2025-10-16 Added list of components
    [list.csv]
2025-10-31 please work
    [01.stl, 02.stl, 03.stl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]
